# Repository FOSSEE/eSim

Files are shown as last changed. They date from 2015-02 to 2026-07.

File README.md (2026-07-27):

<p align="center">
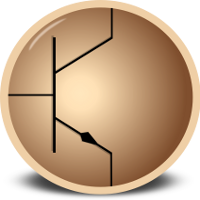
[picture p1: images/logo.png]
eSim Logo
  
</p>

<h1 align="center">eSim — Electronic Circuit Simulation</h1>

<p align="center">
  <strong>An Open-Source EDA Tool for Circuit Design, Simulation, Analysis &amp; PCB Design</strong><br/>
  <em>Developed by <a href="https://www.fossee.in/">FOSSEE Team</a> at <a href="https://www.iitb.ac.in/">IIT Bombay</a></em>
</p>

<p align="center">
  
  
  
  
</p>

<p align="center">
  
  
  
  
  
  
  
</p>

<p align="center">
  <a href="#-features">Features</a> •
  <a href="#%EF%B8%8F-architecture">Architecture</a> •
  <a href="#-installation">Installation</a> •
  <a href="#-project-structure">Project Structure</a> •
  <a href="#-tech-stack">Tech Stack</a> •
  <a href="#-contributing">Contributing</a> •
  <a href="#-license">License</a>
</p>

---

## 📖 About

**eSim** is a free and open-source EDA (Electronic Design Automation) tool for circuit design, simulation, analysis, and PCB design. It is an integrated tool built using open-source software such as **KiCad**, **Ngspice**, **GHDL**, and **Makerchip**, providing a seamless workflow from schematic capture to simulation results.

eSim is designed for electronics engineers, students, educators, and hobbyists who want a powerful yet cost-free alternative to proprietary EDA tools. It supports analog, digital, and **mixed-signal simulations**, including microcontroller integration.

<p align="center">
  <b>📥 Download:</b> <a href="https://esim.fossee.in/downloads">v2.5 Release</a> &nbsp;&nbsp;|&nbsp;&nbsp; 
  <b>📄 Manual:</b> <a href="https://static.fossee.in/esim/manuals/eSim_Manual_2.5.pdf">PDF Guide</a> &nbsp;&nbsp;|&nbsp;&nbsp; 
  <b>📚 Docs:</b> <a href="https://esim.readthedocs.io/en/latest/">ReadTheDocs</a>
</p>

---

## ✨ Features

| Category | Feature | Description |
|:---|:---|:---|
| • **Design** | Schematic Capture | Draw circuit schematics using KiCad's schematic editor with eSim's custom symbol libraries |
| • **Conversion** | KiCad to Ngspice | Convert KiCad schematics to Ngspice-compatible netlists for simulation |
| • **Simulation** | Ngspice Engine | Run DC, AC, Transient, and other SPICE analyses with real-time interactive plots |
| • **Analysis** | Waveform Plotting | Visualize simulation results with matplotlib-based Python plots and Ngspice native plots |
| • **Model Editor** | Device Models | Create and edit SPICE device models (Diodes, BJTs, MOSFETs, JFETs, IGBTs, etc.) |
| • **Subcircuits** | Subcircuit Builder | Build, manage, and upload reusable subcircuit blocks — **741+ ICs** in `SubcircuitLibrary` |
| • **Mixed-Signal** | NGHDL Integration | Interface VHDL digital models (via GHDL) with analog Ngspice simulations |
| • **Verilog** | Makerchip + NgVeri | Use Makerchip IDE for Verilog/TL-Verilog design and convert to Ngspice models |
| • **PCB** | Layout Design | Design PCB layouts using KiCad's PCB editor with eSim's footprint libraries |
| • **Converters** | Schematic Import | Convert PSpice and LTSpice schematics/libraries to KiCad-compatible formats |
| • **Modelica** | Ngspice-to-Modelica | Convert Ngspice netlists to Modelica models for OpenModelica simulation |
| • **SKY130 PDK** | SkyWater 130nm | Support for SkyWater SKY130 open-source Process Design Kit |
| • **IHP PDK** | IHP OpenPDK | Integration with IHP SG13G2 open-source PDK for SiGe BiCMOS |

---

## 🏗️ Architecture

### High-Level System Architecture

```mermaid
graph TB
    %% Styling
    classDef ui fill:#2A3F54,stroke:#1ABB9C,stroke-width:2px,color:#fff
    classDef core fill:#3E536C,stroke:#3498DB,stroke-width:2px,color:#fff
    classDef engine fill:#1F2D3D,stroke:#E74C3C,stroke-width:2px,color:#fff
    classDef data fill:#E9F0F5,stroke:#95A5A6,stroke-width:1px,color:#333
    
    subgraph UI ["User Interface (PyQt6)"]
        A[Application Main Window]:::ui
        PE[Project Explorer]:::ui
        DA[Dock Area Workspace]:::ui
        TE[Time Explorer]:::ui
        CON[Console Widget]:::ui
        
        A --> PE & DA & TE & CON
    end

    subgraph CORE ["Core Python Modules"]
        K2N[KiCad-to-Ngspice]:::core
        SIM[Ngspice Simulator]:::core
        PLT[Matplotlib Plotter]:::core
        ME[Model Editor]:::core
        SC[Subcircuit Builder]:::core
        
        DA --> K2N & SIM & ME & SC
    end

    subgraph INTEGRATION ["Mixed-Signal & External APIs"]
        NGHDL[NGHDL Interface]:::core
        MKR[Makerchip/NgVeri]:::core
        MOD[Modelica Converter]:::core
        CONV[PSpice/LTSpice Converter]:::core
        
        DA --> NGHDL & MKR & MOD & CONV
    end

    subgraph ENGINES ["Simulation & EDA Engines"]
        KICAD[KiCad Eeschema]:::engine
        PCB[KiCad Pcbnew]:::engine
        NGSPICE[Ngspice Backend]:::engine
        GHDL[GHDL Simulator]:::engine
        VER[Verilator]:::engine
        OM[OpenModelica]:::engine
    end

    %% Data Flow
    XML[(Netlist / XML)]:::data
    RAW[(Raw Data / txt)]:::data
    VHDL[(VHDL Files)]:::data
    
    K2N -- Generates --> XML
    XML -- Consumed by --> NGSPICE
    SIM -- Triggers --> NGSPICE
    NGSPICE -- Outputs --> RAW
    RAW -- Parsed by --> PLT
    
    NGHDL -- Compiles --> VHDL
    VHDL -- Simulated by --> GHDL
    GHDL -- Co-simulates --> NGSPICE
    
    MKR -- Verilog/TL-V --> VER
    
    KICAD -- Schematic --> K2N
    KICAD -- Netlist --> PCB
```

*For detailed simulation workflows, sub-system operations, and system flowcharts, please refer to our [Architecture & Workflows Guide](ARCHITECTURE.md).*

---

## 📂 Project Structure

### Root Directory

| Path | Type | Description |
|:-----|:-----|:---|
| `src/` | 📁 Directory | **Core application source code** — all Python modules for the eSim GUI and backend |
| `library/` | 📁 Directory | **Component libraries** — device models, KiCad symbols, subcircuits, and PDK data |
| `nghdl/` | 📁 Directory | **NGHDL module** — Ngspice-GHDL interface for mixed-signal VHDL simulation |
| `Examples/` | 📁 Directory | **42 example projects** — ready-to-simulate circuits (RC, BJT, Op-Amp, Mixed-Signal, etc.) |
| `images/` | 📁 Directory | **UI assets** — application icons, toolbar images, logos, and splash screen |
| `scripts/` | 📁 Directory | **Launch & setup scripts** — shell scripts for Linux installation and launching |
| `docs/` | 📁 Directory | **Sphinx documentation** — RST files for ReadTheDocs auto-generated developer docs |
| `code/` | 📁 Directory | **Sphinx autodoc config** — mirrors `src/` structure for API documentation generation |
| `flatpak/` | 📁 Directory | **Flatpak packaging** — manifest and wrapper scripts for universal Linux distribution |
| `appimage/` | 📁 Directory | **AppImage packaging** — build scripts for portable Linux AppImage bundles |
| `docker-launcher/` | 📁 Directory | **Docker support** — Dockerfile, launcher script, and CI workflows for containerized builds |
| `snap/` | 📁 Directory | **Snap packaging** — `snapcraft.yaml` for building Snap packages |
| `ihp/` | 📁 Directory | **IHP PDK integration** — install script, `.spiceinit` config, NMOS example, and ngspice latest installer for IHP SG13G2 SiGe BiCMOS PDK |
| `patches/` | 📁 Directory | **Source patches** — patch files for modifying Ngspice/GHDL behavior in sandboxed environments |
| `.github/` | 📁 Directory | **GitHub config** — issue templates, PR templates, and CI/CD workflow definitions |
| `setup.py` | 📄 File | Python package configuration for pip installation |
| `requirements.txt` | 📄 File | Python dependency list (PyQt6, matplotlib, numpy, scipy, etc.) |
| `conf.py` | 📄 File | Sphinx documentation configuration |
| `VERSION` | 📄 File | Current version identifier (`2.5`) |
| `INSTALL` | 📄 File | Detailed multi-platform installation instructions |
| `LICENSE` | 📄 File | GNU General Public License v3.0 |

### Source Code (`src/`) — Detailed Module Breakdown

```
src/
├── frontEnd/               # GUI & Main Application
│   ├── Application.py      # Main window, toolbar setup, menu actions (960 lines)
│   ├── DockArea.py          # Tabbed dock workspace for editors/simulators (24K)
│   ├── ProjectExplorer.py   # File tree browser for project navigation (20K)
│   ├── TimeExplorer.py      # Project snapshot/version management (8K)
│   ├── TerminalUi.py        # Embedded terminal widget (5K)
│   └── Workspace.py         # Workspace selection dialog (6K)
│
├── kicadtoNgspice/          # KiCad-to-Ngspice Conversion Engine
│   ├── KicadtoNgspice.py    # Main conversion controller & UI (41K)
│   ├── Convert.py           # Netlist parsing and SPICE generation (40K)
│   ├── Analysis.py          # Analysis type configuration (DC, AC, Transient) (32K)
│   ├── DeviceModel.py       # Device model parameter handling (56K)
│   ├── Source.py             # Source component configuration (15K)
│   ├── Processing.py         # Netlist processing pipeline (26K)
│   ├── SubcircuitTab.py      # Subcircuit selection in converter (9K)
│   ├── Microcontroller.py    # Microcontroller model support (10K)
│   ├── Model.py              # Model file handling (6K)
│   └── TrackWidget.py        # UI tracking widget (1K)
│
├── ngspiceSimulation/       # Simulation Engine & Plotting
│   ├── NgspiceWidget.py     # Ngspice process management & execution (16K)
│   ├── plot_window.py       # matplotlib-based waveform plotter (66K)
│   ├── plotting_widgets.py  # Custom plot controls and widgets (8K)
│   └── data_extraction.py   # Simulation data file parser (11K)
│
├── modelEditor/             # SPICE Model Editor
│   └── ModelEditor.py       # GUI for creating/editing device models (33K)
│
├── subcircuit/              # Subcircuit Management
│   ├── Subcircuit.py        # Subcircuit manager main window (3K)
│   ├── newSub.py            # Create new subcircuit (3K)
│   ├── openSub.py           # Open existing subcircuit (1K)
│   ├── uploadSub.py         # Upload subcircuit to library (4K)
│   └── convertSub.py        # Subcircuit format conversion (2K)
│
├── maker/                   # Makerchip & NgVeri Integration
│   ├── Maker.py             # Makerchip IDE integration (23K)
│   ├── NgVeri.py            # Verilog-to-Ngspice model generator (17K)
│   ├── ModelGeneration.py   # Auto model generation pipeline (48K)
│   ├── createkicad.py       # KiCad symbol creation for models (14K)
│   ├── makerchip.py         # Makerchip cloud IDE connector (3K)
│   └── Appconfig.py         # Maker-specific configuration (2K)
│
├── converter/               # Schematic Format Converters
│   ├── pspiceToKicad.py     # PSpice schematic importer (5K)
│   ├── ltspiceToKicad.py    # LTSpice schematic importer (6K)
│   ├── libConverter.py      # Library format converter (3K)
│   ├── LtspiceLibConverter.py # LTSpice library converter (4K)
│   ├── browseSchematic.py   # File browser for schematics (550B)
│   ├── LTSpiceToKiCadConverter/ # LTSpice conversion engine
│   └── schematic_converters/    # Additional schematic parsers
│
├── ngspicetoModelica/       # 📐 Ngspice-to-Modelica Converter
│   ├── NgspicetoModelica.py # Core conversion engine (54K)
│   └── ModelicaUI.py        # Modelica converter GUI (10K)
│
├── configuration/           # ⚙️ Application Configuration
│   └── Appconfig.py         # Global config, paths, process tracking (4K)
│
├── projManagement/          # 📋 Project Management
│   ├── Kicad.py             # KiCad integration (launch schematic/PCB editor) (9K)
│   ├── Validation.py        # Tool and file validation utilities (7K)
│   ├── Worker.py            # Background process/thread management (3K)
│   ├── newProject.py        # New project creation logic (5K)
│   └── openProject.py       # Open existing project logic (3K)
│
└── browser/                 # 📖 Help & Documentation
    ├── Welcome.py           # Welcome screen display (941B)
    └── UserManual.py        # User manual viewer (731B)
```

### Library Directory (`library/`) — Component Libraries

| Path | Description |
|:-----|:---|
| `deviceModelLibrary/` | SPICE device models organized by type: Diode, BJT (Transistor), MOSFET (MOS), JFET, IGBT, LEDs, Switches, Transmission Lines, and user libraries |
| `kicadLibrary/` | KiCad schematic symbols (`eSim-symbols/`), footprint libraries (`kicad_eSim-Library/`), and project templates |
| `SubcircuitLibrary/` | **741+ reusable subcircuit ICs** — logic gates, flip-flops, op-amps, regulators, timers, multiplexers, shift registers, comparators, multipliers, PDK-specific IPs, and more (see [Subcircuit Library](#-subcircuit-library) section) |
| `modelParamXML/` | XML parameter definitions for device model editor forms |
| `ngspicetoModelica/` | Mapping files for Ngspice-to-Modelica component translation |
| `browser/` | HTML/resource files for the built-in help browser |
| `tlv/` | TL-Verilog support files for Makerchip integration |

### NGHDL Module (`nghdl/`) — Mixed-Signal Interface

| Path | Description |
|:-----|:---|
| `src/ngspice_ghdl.py` | Core interface: manages VHDL upload, GHDL compilation, and Ngspice code model creation |
| `src/model_generation.py` | Generates C code models from VHDL port definitions for Ngspice |
| `src/createKicadLibrary.py` | Auto-generates KiCad symbols from VHDL entity definitions |
| `src/ghdlserver/` | GHDL foreign interface server for inter-process communication with Ngspice |
| `install-nghdl.sh` | Automated installer for NGHDL dependencies (GHDL, Verilator, Ngspice) |
| `Example/` | Example VHDL models and mixed-signal simulation projects (including **Microwatt NGHDL co-simulation**) |

### IHP PDK Integration (`ihp/`) — SiGe BiCMOS Open PDK

| Path | Description |
|:-----|:---|
| `ihp-install-script.sh` | Automated installer for IHP SG13G2 open-source SiGe BiCMOS PDK |
| `install-ngspice-latest.sh` | Script to build and install the **latest ngspice** from source (with OSDI support) — requires eSim/NGHDL to be installed first |
| `.spiceinit` | Pre-configured `.spiceinit` file for IHP-Open-PDK; automatically placed in the home directory after configuration |
| `example.cir` | NMOS DC test circuit demonstrating IHP PDK SPICE simulation |

---

## 🛠️ Tech Stack

| Layer | Technology | Purpose |
|:---|:---|:---|
| **Language** |  | Core application logic |
| **GUI Framework** |  | Desktop GUI (windows, dialogs, toolbars, docks) |
| **Plotting** |  | Waveform visualization and data plotting |
| **Numerics** |   | Numerical computation and signal processing |
| **Schematic & PCB** |  | Schematic capture and PCB layout design |
| **SPICE Simulation** |  | Analog/mixed-signal circuit simulation engine |
| **VHDL Simulation** |  | VHDL analysis, compilation, and simulation |
| **Verilog** |  | Verilog HDL simulation and model generation |
| **HDL Cloud IDE** |  | Online Verilog/TL-Verilog IDE integration |
| **Modelica** |  | Multi-domain modeling and simulation |
| **PDK** |   | SkyWater 130nm & IHP SiGe BiCMOS open-source PDKs |
| **Packaging** |   | Cross-distribution Linux packaging & containers |
| **Documentation** |   | Auto-generated developer documentation |
| **CI/CD** |  | Automated builds, Docker images, and releases |

### Key Python Dependencies

| Package | Version | Purpose |
|:---|:---|:---|
| `PyQt6` | ≥ 6.5.0 | GUI framework |
| `matplotlib` | 3.7.5 | Waveform plotting |
| `numpy` | 1.24.4 | Numerical computation |
| `scipy` | 1.10.1 | Scientific computing |
| `pillow` | 12.2.0 | Image processing |
| `hdlparse` | 1.0.4 | HDL file parsing |
| `watchdog` | 4.0.2 | File system monitoring |
| `pyparsing` | 3.1.4 | Parser building toolkit |

---

## 💻 Installation

### Supported Platforms

| Platform | Method | Status |
|:---|:---|:---:|
| **All Linux** (Fedora, Ubuntu, openSUSE, Arch, etc.) | Flatpak | ✅ Recommended |
| **Ubuntu** 22.04 / 23.04 / 24.04 LTS | Native Installer | ✅ Supported |
| **Windows** 8 / 10 / 11 | Windows Installer | ✅ Supported |
| **Docker** (any OS) | Docker Container | ✅ Supported |

### 🐧 Linux — Flatpak (Recommended for all distributions)

```bash
# 1. Install Flatpak (if not already installed)
# Fedora:    sudo dnf install flatpak
# Ubuntu:    sudo apt install flatpak
# openSUSE:  sudo zypper install flatpak
# Arch:      sudo pacman -S flatpak

# 2. Add Flathub repository
flatpak remote-add --if-not-exists flathub https://dl.flathub.org/repo/flathub.flatpakrepo

# 3. Install eSim
flatpak install flathub org.fossee.eSim

# 4. Run eSim
flatpak run org.fossee.eSim
```

> **⚠️ Flatpak Limitations:** NGHDL, Makerchip, and SKY130 PDK are not included in the Flatpak build. For full mixed-signal support, use the Ubuntu native installer.

### 🐧 Ubuntu — Native Installer

```bash
# 1. Download and extract eSim
unzip eSim-2.5.zip
cd eSim-2.5

# 2. Install eSim with all dependencies
chmod +x install-eSim.sh
./install-eSim.sh --install

# 3. Run eSim
esim
# Or double-click the eSim desktop icon
```

### 🪟 Windows

1. Download the eSim installer from [esim.fossee.in/downloads](https://esim.fossee.in/downloads)
2. Disable antivirus temporarily (if required)
3. **Important:** Remove MinGW/MSYS from the PATH environment variable if previously installed
4. Run the installer and follow the on-screen instructions
5. Launch eSim from the Start Menu or desktop shortcut

### 🐋 Docker

Refer to the [Docker Launcher README](docker-launcher/README.md) for instructions on running eSim in a containerized environment.

> **Note:** The Docker image now includes `libreadline-dev` to fix a build issue on recent Ubuntu base images.

### 📦 Build from Source (Flatpak)

```bash
cd eSim
flatpak-builder build flatpak/org.fossee.eSim.yml --install --user
```

> 📖 For comprehensive installation instructions, see the [INSTALL](INSTALL) file.

### ⚗️ IHP PDK — Latest Ngspice from Source

If you need the latest Ngspice with OSDI support for IHP PDK simulations:

```bash
# Requires eSim/NGHDL to be installed first
chmod +x ihp/install-ngspice-latest.sh
./ihp/install-ngspice-latest.sh
```

---

## 🔄 CI/CD & Packaging

| Workflow | File | Purpose |
|:---|:-----|:---|
| Docker Image Build | `.github/workflows/docker-image.yml` | Builds and publishes the eSim Docker image |
| Docker Launcher Build | `.github/workflows/docker-launcher-build.yml` | Builds the cross-platform Python launcher |
| Ubuntu Release | `.github/workflows/release_ubuntu.yml` | Automated Ubuntu `.deb` package builds |

| Packaging Format | Directory | Description |
|:---|:---|:---|
| Flatpak | `flatpak/` | Universal Linux package via Flathub |
| AppImage | `appimage/` | Portable single-file Linux executable |
| Snap | `snap/` | Ubuntu Snap Store package |
| Docker | `docker-launcher/` | Containerized distribution with GUI forwarding |

---

## 📋 Example Projects

eSim ships with **42 ready-to-simulate example projects** in the `Examples/` directory:

<details>
<summary><b>📂 Click to expand full example list</b></summary>

| # | Category | Example | Description |
|:-:|:---|:---|:---|
| 1 | 🔌 Basic | `RC` | RC circuit transient analysis |
| 2 | 🔌 Basic | `RL` | RL circuit transient analysis |
| 3 | 🔌 Basic | `RLC` | RLC circuit resonance analysis |
| 4 | 🔌 Basic | `Series_Resonance` | Series RLC resonance |
| 5 | 🔌 Basic | `Parallel_Resonance` | Parallel RLC resonance |
| 6 | 💡 Diodes | `Diode_characteristics` | Diode I-V characteristics |
| 7 | 💡 Diodes | `Halfwave_Rectifier` | Half-wave rectifier circuit |
| 8 | 💡 Diodes | `Fullwavebridgerectifier` | Full-wave bridge rectifier |
| 9 | 💡 Diodes | `Clippercircuit` | Diode clipper circuit |
| 10 | 💡 Diodes | `Clampercircuit` | Diode clamper circuit |
| 11 | 💡 Diodes | `Zener_Characteristic` | Zener diode characteristics |
| 12 | 🔋 BJT | `BJT_CE_config` | BJT common-emitter configuration |
| 13 | 🔋 BJT | `BJT_CB_config` | BJT common-base configuration |
| 14 | 🔋 BJT | `BJT_amplifier` | BJT amplifier circuit |
| 15 | 🔋 BJT | `BJT_Biascircuit` | BJT bias circuit design |
| 16 | 🔋 BJT | `BJT_Frequency_Response` | BJT frequency response analysis |
| 17 | 📟 FET | `FET_Characteristic` | FET output characteristics |
| 18 | 📟 FET | `FET_Amplifier` | FET amplifier circuit |
| 19 | 📟 FET | `FrequencyResponse_JFET` | JFET frequency response |
| 20 | 🎛️ Op-Amp | `InvertingAmplifier` | Op-amp inverting amplifier (LM741) |
| 21 | 🎛️ Op-Amp | `Differentiator` | Op-amp differentiator circuit |
| 22 | 🎛️ Op-Amp | `Integrator_LM_741` | Op-amp integrator |
| 23 | 🎛️ Op-Amp | `Precision_Rectifiers_using_LM741` | Precision rectifier circuits |
| 24 | 🔲 Digital | `BasicGates` | Basic logic gates |
| 25 | 🔲 Digital | `Half_Adder` | Half-adder circuit |
| 26 | 🔲 Digital | `FullAdder` | Full-adder circuit |
| 27 | 🔲 Digital | `JK_Flipflop` | JK flip-flop circuit |
| 28 | 🔲 Digital | `4_bit_JK_ff` | 4-bit JK flip-flop counter |
| 29 | 🔲 Digital | `CMOS_NAND_Gate` | CMOS NAND gate |
| 30 | 🔲 Digital | `Analysis_Of_Digital_IC` | Digital IC analysis |
| 31 | ⏱️ Timers | `Astable555` | 555 timer astable mode |
| 32 | ⏱️ Timers | `Monostable555` | 555 timer monostable mode |
| 33 | 🔁 SCR | `HalfwaveRectifier_SCR` | SCR half-wave rectifier |
| 34 | 🔁 SCR | `FullwaveRectifier_SCR` | SCR full-wave rectifier |
| 35 | 📡 Filters | `High_Pass_Filter` | High-pass filter design |
| 36 | 📡 Filters | `Low_Pass_Filter` | Low-pass filter design |
| 37 | ⚡ Regulators | `7805VoltageRegulator` | 7805 voltage regulator |
| 38 | ⚡ Regulators | `7812VoltageRegulator` | 7812 voltage regulator |
| 39 | 🌀 Oscillators | `UJT_Relaxation_Oscillator` | UJT relaxation oscillator |
| 40 | 🌀 Oscillators | `Phase_Locked_Loop` | PLL circuit |
| 41 | 🔀 Mixed-Signal | `Mixed_Signal` | Mixed analog-digital simulation (NGHDL) |
| 42 | 🔌 Power | `Transformer` | Transformer circuit analysis |

</details>

---

## 📦 Subcircuit Library

The `library/SubcircuitLibrary/` directory contains **741+ verified subcircuit models** contributed by the community. These can be directly used in eSim simulations as subcircuit blocks.

<details>
<summary><b>📂 Click to expand subcircuit categories</b></summary>

| Category | Examples |
|:---|:---|
| **Logic Gates & Buffers** | 74HC08, 74HC32, 74HC86, SN74LS00, IC74HC00, INVCMOS, CMOS_NAND, SNx4HC03 |
| **Flip-Flops & Latches** | 74LS379, CD4095BMS, JK flip-flops (74LS112, IC74HC107), D flip-flops, SR latches |
| **Shift Registers** | 74hc589, 74HCT594, 74LS298, 74LS399, SN74LS295B, SN74LS194 |
| **Multiplexers / Demultiplexers** | 74LS150 (16:1 MUX), 74HC157, CD4051_sub, SN74LS451, 74ls670 |
| **Counters & Dividers** | CD4017B, CD4026B, CD4029B, 74ls93, 74ls181, SN74LS461, DM74ls173 |
| **Encoders / Decoders** | SN74LS247, SN74LS353, MM74C923, CD4099B, CD4089B, LM3914 |
| **Op-Amps & Comparators** | LM358_Sub, LM741, LM311, LM393, LT1010, lmh6702, opa656, ths4303, ths4541 |
| **Voltage Regulators** | LM7806, LM7812, LP2950, LP2951, LM317_sub, MCP1700, TCA965, MC1569_Sub |
| **Audio Amplifiers** | MC1306_Sub, MC1554_Sub, LM386, LM833, TDA2003A_sub |
| **RF / IF Amplifiers** | MC1510_sub, MC1545_Sub, MC1550_Sub, vca821 |
| **Multipliers & Modulators** | ad834, ad8307, MC1595_Sub, MC1596_Sub, cppll |
| **Motor Drivers & Power ICs** | L298N, IR2110, IR2130, IP5328P, TP4056, MCP73831, TL494 |
| **CA-Series ICs** | CA3005, CA3018, CA3019, CA3022, CA3028A, CA3036, CA3054, CA3080, CA3094 |
| **SN74-Series ICs** | SN74AS303, SN74AS304, SN74AS305, SN74LS247, SN74LS451, SN74S268, SN74S532, SN74S536, SN74278 |
| **MC-Series ICs** | MC1306_Sub, MC1510_sub, MC1545_Sub, MC1550_Sub, MC1554_Sub, MC1569_Sub, MC1595_Sub, MC1596_Sub |
| **CD/CMOS Series** | CD4016, CD4026B, CD4029B, CD4089B, CD4095BMS, CD4099B, CD74HC563, CD74HCT241 |
| **ADC / DAC** | 3bit_flash_adc, DAC0800, 10bitDAC |
| **Timers** | NE556 (dual 555), lm555n, MC1455B_IC |
| **Miscellaneous** | SN54170, LM2902, LM2904, LM2917, LM2941, TL783, _TL783 |

</details>

> 💡 **Contributing a Subcircuit?** Follow the guidelines in [CONTRIBUTING.md](CONTRIBUTING.md). Each subcircuit should include a `.sub` SPICE file, a KiCad schematic (`.kicad_sch`), and a test circuit (`.cir`).

---

## 🤝 Contributing

We welcome contributions from the community! Whether it's bug fixes, new features, documentation improvements, or example circuits — every contribution matters.

### How to Contribute

```mermaid
flowchart LR
    A["🍴 Fork<br/>Repository"] --> B["🌿 Create<br/>Branch"]
    B --> C["💻 Make<br/>Changes"]
    C --> D["✅ Commit &<br/>Push"]
    D --> E["📬 Open<br/>Pull Request"]

    style A fill:#6c5ce7,color:#fff
    style B fill:#00b894,color:#fff
    style C fill:#0984e3,color:#fff
    style D fill:#fdcb6e,color:#333
    style E fill:#e17055,color:#fff
```

1. **Fork** the repository to your GitHub account
2. **Clone** your fork:
   ```bash
   git clone https://github.com/<your-username>/eSim.git
   ```
3. **Create a new branch** for your changes:
   ```bash
   git checkout -b feature/your-feature-name
   ```
4. **Make your changes** and commit with a descriptive message:
   ```bash
   git add <files>
   git commit -m "Fixes issue #<number> - Brief description of changes"
   ```
5. **Push** to your fork and **open a Pull Request**:
   ```bash
   git push origin feature/your-feature-name
   ```

> **📌 Guidelines:**
> - Each PR should reference an existing issue
> - One commit per pull request (squash if needed)
> - Follow [PEP 8](https://www.python.org/dev/peps/pep-0008/) code style
> - Include a commit body describing what you changed and why

For detailed contribution guidelines, see [CONTRIBUTING.md](CONTRIBUTING.md).

---

## 👥 Contributors

A huge thank you to all **149+ amazing people** who have contributed to eSim! 🎉

<table align="center" style="border:none;">
  <tr>
    <td align="center" width="250" style="border:none;">
      <a href="https://github.com/Eyantra698Sumanto" style="text-decoration:none;">
        Sumanto Kar<br/>
        <b>🥇 Sumanto Kar</b>
      </a><br/>
      <sub>Lead Maintainer · 320 commits</sub>
    </td>
    <td align="center" width="250" style="border:none;">
      <a href="https://github.com/rahulp13" style="text-decoration:none;">
        Rahul Paknikar<br/>
        <b>🥈 Rahul Paknikar</b>
      </a><br/>
      <sub>265 commits</sub>
    </td>
    <td align="center" width="250" style="border:none;">
      <a href="https://github.com/fahim-oscad" style="text-decoration:none;">
        Fahim Khan<br/>
        <b>🥉 Fahim Khan</b>
      </a><br/>
      <sub>244 commits</sub>
    </td>
  </tr>
</table>

<p align="center">
  <a href="https://github.com/fossee/esim/graphs/contributors">
    Contributors
  </a>
</p>

<p align="center"><em>149+ contributors and counting! <a href="https://github.com/fossee/esim/graphs/contributors">View all contributors →</a></em></p>

---

## 📞 Contact & Support

| Channel | Link |
|:---|:-----|
| 📧 **Email** | [contact-esim@fossee.in](mailto:contact-esim@fossee.in) |
| 🌐 **Website** | [esim.fossee.in](https://esim.fossee.in/) |
| 💬 **Forum** | [forums.fossee.in](https://forums.fossee.in/) |
| 📞 **Contact Page** | [esim.fossee.in/contact-us](https://esim.fossee.in/contact-us) |
| 📄 **User Manual** | [eSim Manual v2.5 (PDF)](https://static.fossee.in/esim/manuals/eSim_Manual_2.5.pdf) |
| 📚 **Developer Docs** | [esim.readthedocs.io](https://esim.readthedocs.io/en/latest/) |

---

## 📝 Recent Changes

A summary of notable changes since the last README update (June 2026):

### 🔧 IHP PDK Enhancements (June 2026)
- Added `ihp/install-ngspice-latest.sh` — a script to build the latest Ngspice from source with OSDI support for IHP PDK users
- Added `ihp/.spiceinit` — pre-configured Ngspice initialization file for IHP-Open-PDK; the install script now correctly places it in the user's home directory
- Added `ihp/example.cir` — an NMOS DC test circuit demonstrating IHP PDK simulation

### 🧩 Subcircuit Library Expansion (June–July 2026)
Over **100 new subcircuit ICs** were contributed and verified, bringing the total to **741+** entries in `library/SubcircuitLibrary/`. Highlights include:
- **CA-series ICs**: CA3005, CA3018, CA3019, CA3022, CA3028A, CA3036, CA3054 (and moved CA3020, CA3021, etc. from misplaced locations)
- **MC-series analog ICs**: MC1306_Sub (audio amp), MC1510_sub (RF/IF amp), MC1545_Sub (video amp), MC1550_Sub (RF/IF amp), MC1554_Sub (audio amp), MC1569_Sub (voltage regulator), MC1595_Sub (4-quadrant multiplier), MC1596_Sub (balanced modulator/demodulator)
- **Analog ICs from PR #604 (Farhana)**: LT1010, vca821, ths4541, ths4303, opa656, lmh6702, cppll, ad834, ad8307, 3bit_flash_adc
- **Power/control ICs**: L298N (motor driver), IR2110, IR2130 (gate drivers), IP5328P (power bank IC), TP4056 (Li-ion charger), MCP73831 (Li-Po charger), TL494 (PWM controller), TL783, LP2950, LP2951
- **Voltage regulators**: LM2941, LM7806, MCP1700, TCA965
- **Op-amps / comparators**: LM2902, LM2904, LM2917, LM1815
- **SN74-series digital ICs**: SN74AS303/304/305, SN74LS247, SN74LS295B, SN74LS353, SN74LS451, SN74LS461, SN74LS498, SN74S268, SN74S532, SN74S536, SN74278
- **TTL/CMOS logic**: 74LS112, 74LS150, 74LS298, 74LS379, 74LS399, 74hc589, 74HCT594, CD4095BMS, CD4016, CD4026B, CD4029B, CD4089B, CD4099B, SN54170, MM74C923, LM3914
- **Additional digital ICs**: 74ls93, 74ls175, 74ls181, 74ls374, 74ls670, 74lv157, DM74ls173, sn74ls244, sn5470, 4024bc

### 🔀 Library Reorganization (July 2026)
- **PR #591**: Cleaned up misplaced subcircuits — moved `CA3020`, `LM108`, `LM3080`, `MC1496`, `NE556`, `TL03xA`, `UA702M` from a duplicate location into the canonical `library/SubcircuitLibrary/` path
- **Subcircuit files** from `SUBCKT/` directory moved to `library/SubcircuitLibrary/` (June 2026)

### 🔬 NGHDL — New Microwatt Example (June 2026)
- Added a **Microwatt NGHDL co-simulation example** in `nghdl/Example/` demonstrating mixed-signal simulation with the open-source Microwatt POWER ISA soft-core processor (via PR #569)

### 🐋 Docker — Build Fix (June 2026)
- Added `libreadline-dev` to the Dockerfile to resolve a build failure on newer Ubuntu base images

### 🛠️ Bug Fix — Workspace Newline (June 2026)
- Fixed workspace newline handling issue (PR #469)

---

## 📄 License

eSim is licensed under the **GNU General Public License v3.0**. See [LICENSE](LICENSE) for details.

<p align="center">
  <strong>Built with ❤️ by the <a href="https://www.fossee.in/">FOSSEE Team</a> at <a href="https://www.iitb.ac.in/">IIT Bombay</a></strong>
</p>

<p align="center">
  <a href="https://esim.fossee.in/">
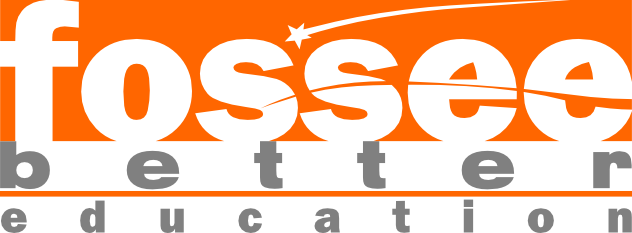
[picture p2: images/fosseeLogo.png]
FOSSEE Logo
    
  </a>
  &nbsp;&nbsp;&nbsp;&nbsp;
  <a href="https://www.iitb.ac.in/">
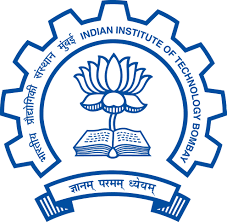
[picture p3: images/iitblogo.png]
IIT Bombay Logo
    
  </a>
</p>

<p align="center">
  <sub>⭐ If you find eSim useful, consider giving it a star on GitHub!</sub>
</p>

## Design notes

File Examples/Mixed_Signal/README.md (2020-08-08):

Instructions on how to use the following examples provided in this directory:

These examples are supported by the NGHDL feature.
In order to simulate the examples listed above, follow the below instructions.

1. Go to eSim main window -> Click on NGHDL icon from the left toolbar, click on the 'browse' button, go to ../nghdl/Example/ and locate which example you wish to simulate.
2. After opening the directory of desired example, locate the vhdl file, click on the "Open" button at the bottom of "Open File" window.
3. Click on 'upload' button in the NGHDL pop-up window. File will be processed in the backend for few seconds. Now exit the NGHDL window.
4. Open the desired example under eSim/Examples/Mixed_Signal/ using the Open Project button, double click on the project when the project is loaded in the "Projects" window.
5. Click on the "Simulation" button on eSim main window.

More examples will be added by eSim team along the way.
If you have a good command on VHDL and electronics, please feel free to contribute.

Note : The Examples in this directory are for demonstration purpose of eSim's Mixed-Signal Simulation feature executing as expected.

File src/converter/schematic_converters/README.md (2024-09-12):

# eSim_PSpice_to_KiCad_Python_Parser

This code is written by Suryavamsi Tenetti, FOSSEE, IIT Bombay and modified by Sumanto Kar and Gloria Nandihal, FOSSEE, IIT Bombay.

This program converts PSpice schematic files (.sch) to KiCad schematic files (.sch)

This program converts PSpice library files (.slb) to KiCad library files (.lib)

USAGE:

-----------------------------------------------
**Make sure the python 3 compiler is installed in the PC**

Run the following command in the terminal in order to install it.

$ sudo apt install python3.7

-----------------------------------------------
**To download the eSim_PSpice_to_KiCad_Python_Parser**

Clone or Download the *eSim_PSpice_to_KiCad_Python_Parser* from the Git in the Home folder(or any other folder) of the local computer.

-----------------------------------------------
**To convert the PSpice library(.slb) files to KiCad library(.lib) files**

Set the path where the *libparser.py* file is located. It is located at */eSim_PSpice_to_KiCad_Python_Parser/lib/PythonLib*

$ python3 libParser.py <path to the pspice lib file(slb)> <output_library_name_without_extension> 

Example:
$ python3 libParser.py ~/Home/eSim_PSpice_to_KiCad_Python_Parser/libray/analog.slb analog

This will create analog.lib file and save it in the path </Home/eSim_PSpice_to_KiCad_Python_Parser/libray/>

-----------------------------------------------
**To convert the PSpice schematic files to KiCad schematic files**

Set the path where the *parser.py* file is located. It is located at */eSim_PSpice_to_KiCad_Python_Parser/lib/PythonLib*

$ python3 parser.py <path/to/pspice-schematic.sch> <path/to/output-project-name-without-extension>

Example:
$ python3 parser.py ~/Desktop/pspice/rc.sch ~/Desktop/convert/rc

This will create a folder rc at the location /Desktop/convert/. The directory will have  rc.sch, rc.proj and rc.pro.
The directory will have read only access. You need to use chmod command to change the access.

--------------------------------------------------------
**To change the access of the file and folder**

Use this command to change access to the files:

chmod <options> <permissions> <file name>
Example:
chmod u=rwx,g=rx,o=r myfile

You can also use: 

sudo chmod 777 filename.

Example: sudo chmod 777 ~/Desktop/convert/rc

-----------------------------------------------
**To open the KiCad schematic file in eSim** 

1. Open eSim.
2. Create a *new project*.
3. Open the schematic using *open schematic* option.
4. Make sure all the libraries are loaded (9k+) using *Place component* option in eeschema.
5. Append the schematic using *Append Schematic* option from the file menu
6. Go to the directory where your files are converted.
7. Select the KiCad coverted schematic file (.sch). Click on Open.
8. To simulate, follow the instructions available on the eSim webpage
    https://esim.fossee.in/pspice-to-kicad
-----------------------------------------------
**To load the KiCad libraries**

If all the libraries in eeschema are not loaded, follow these steps:
1. In eeschema, select *Preferences* option.
2. Click on the *Component Libraries* in the drop down list.
3. A dialog box appears, click on the *Add* option.
4. Go to the path where your library to be added is saved.
5. Select the library to be added and click on *Open* button.
6. Close the dialog box.
-----------------------------------------------
**To add libraries in the parser.py**

Open the *parser.py* python file. It is located at */eSim_PSpice_to_KiCad_Python_Parser/lib/PythonLib*
Type and add the libraries in the variables *"descr"* and *"prodescr"*

-----------------------------------------------
**WARNING**

1. Filenames should NOT contain whitespaces or tabs.
2. All required libraries SHOULD be added.
3. Use proper file format.
4. DO NOT TRY TO CONVERT library file as schematic file or vice versa.
5. Try adding libraries in the parser.py while getting error.
6. DO NOT CHANGE any of the files unless and until needed.

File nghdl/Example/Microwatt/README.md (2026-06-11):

# Microwatt eSim Integration

## Overview

This directory contains initial integration support for running the OpenPOWER Microwatt core inside the eSim/NGHDL co-simulation environment.

The integration flow enables Microwatt to be compiled with GHDL and wrapped for NGHDL/XSPICE-based simulation inside eSim.

## Files

### `microwatt_cosim.vhdl`

NGHDL-compatible wrapper for Microwatt.

Exposed ports:

* `clk` : Clock input
* `rst` : Reset input
* `uart_tx` : UART transmit output

### `compile_for_nghdl.sh`

Build script used to:

* Compile Microwatt using GHDL
* Build required helper objects
* Elaborate the wrapper for NGHDL/XSPICE integration

## Build Flow

Run:

```bash
bash esim/compile_for_nghdl.sh
```

Successful compilation generates the NGHDL-compatible elaborated design.

## eSim Workflow

1. Compile Microwatt using the provided script
2. Generate the NGHDL/XSPICE codemodel
3. Import the generated block into eSim
4. Create a schematic using:

   * clock pulse
   * reset pulse
   * UART probe
5. Run transient simulation

## Current Status

* Wrapper compilation successful
* NGHDL integration validated
* Basic schematic-level simulation setup completed

## Future Work

* Add memory and peripheral models
* Expand validation workflows
* Add example system-level designs

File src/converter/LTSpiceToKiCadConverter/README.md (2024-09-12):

# LTSpice To KiCad Converter by eSim Team

This code is referred from the following repository: https://github.com/laurentc2/LTspice2Kicad

This code is authored by Sumanto Kar, FOSSEE, IIT Bombay and the team members.

The repository contains program to convert LTSpice Schematics to KiCad Schematics.

The repository also contains program to convert LTSpice symbol files(.asy) to KiCad symbol files(.lib).

The code is supported by both Windows and Ubuntu(and flavors) Operating System.

## Cloning the repo:

To start with, please clone the repository:</br>
	```
	git clone https://github.com/FOSSEE/LTSpiceToKiCadConverter
	```

## Windows OS

### To Convert the Schematic file

1. Make sure python3 is installed and added to the path
2. Switch to src/Windows directory
3. Paste the LTspice file(.asc format) to be converted here
4. Double Click on the ```Sch_CreateBat.bat``` script
5. The LTspice schematic is converted to eSim(KiCad) schematic and project files
6. The files are saved in the src/Windows in a folder created with name ```LTspice_<schematic_name>```

-----------------------------------------------
### To Convert the .asy file to .lib file

1. Make sure python3 is installed and added to the path
2. Switch to src/Windows directory
3. Run the following command to convert the .asy files contained in a single folder to a .lib file:
	```
	python3 lib_LTspice2Kicad.py <Path to the folder containing the .asy files">
	```
	Example:
	```
	python3 lib_LTspice2Kicad.py "C:\Program Files\LTC\LTspiceXVII\lib\sym\DAC"
	```
	The .asy files will be converted a single .lib file with name LTspice_<folder_name>.lib. 
	For example: LTspice_DAC.lib</br>
4. To convert many folders containg .asy files:</br>
	- Edit the path in the ```lib_LTspice2Kicad.bat``` file using a text editor</br>
	- Save and close it</br>
	- Double click on the Batch files</br>
	- All the converted .lib files will be saved in the src/Windows

## Ubuntu OS

### To Convert the Schematic file

1. Make sure python3 is installed and added to the path
2. Switch to src/Ubuntu directory
3. Run the following command to convert the LTspice(.asc) files to KiCad Schematic(.sch, .pro and .proj) files:
    ```
    python3 sch_LTspice2Kicad.py <Path to the .asc file">
    ```
    For Example:
    ```
    python3 sch_LTspice2Kicad.py "/home/sumanto/Downloads/ltspice/ltspice/27C.asc"
    ```
4. The files are saved in a folder(in the same path where the original .asc file exists) created with name ```LTspice_<schematic_name>```

-----------------------------------------------
### To Convert the .asy file to .lib file

1. Make sure python3 is installed and added to the path
2. Switch to src/Ubuntu directory
3. Run the following command to convert the .asy files contained in a single folder to a .lib file:
	```
	python3 lib_LTspice2Kicad.py <Path to the folder containing the .asy files">
	```
	Example:
	```
	python3 lib_LTspice2Kicad.py "python3 lib_LTspice2Kicad.py /home/sumanto/Downloads/ltspice/libs/DAC"
	```
	The .asy files will be converted and save in src/Ubuntu to a single .lib file with name LTspice_<folder_name>.lib. 
	For example: LTspice_DAC.lib

-----------------------------------------------
### Example LTspice Schematics(.asc) and Symbol libraries(.asy)
The Example LTspice Schematics(.asc) and Symbol Libraries(.asy) are available in the LTspice software.

Please download the software from the official website.

## Converted KiCad Schematics(.sch, .pro, .proj)
The converted examples are available [here](https://github.com/FOSSEE/LTSpiceToKiCadConverter/tree/main/Examples/ConvertedKiCad_Schematics_no_eSim_Plots).

## Converted KiCad Schematics with eSim Simulation Plots
The Converted KiCad Schematics with eSim Simulation Plots are available [here](https://github.com/FOSSEE/LTSpiceToKiCadConverter/tree/main/Examples/ConvertedKiCadSchematics_witheSimPlots).

## Converted KiCad Symbol Library files(.lib)
The converted KiCad Symbol Library files are available [here](https://github.com/FOSSEE/LTSpiceToKiCadConverter/tree/main/Examples/ConvertedLibraries).

## Important Notes/Commands
**To change the access of the file and folder**

Use this command to change access to the files:</br>
	```
		chmod <options> <permissions> <file name>
	```</br> 
Example:</br>
	```
		chmod u=rwx,g=rx,o=r myfile
	```</br> 
You can also use:</br> 
	```	
		sudo chmod 777 filename.
	```</br> 
Example:</br>
	```
	sudo chmod 777 ~/Desktop/convert/rc
	```</br> 

-----------------------------------------------
**To open the KiCad schematic file in [eSim](https://esim.fossee.in/home)** 

1. Open eSim.
2. Create a *new project*.
3. Open the schematic using *open schematic* option.
4. Make sure all the libraries are loaded (9k+) using *Place component* option in eeschema.
5. Append the schematic using *Append Schematic* option from the file menu
6. Go to the directory where your files are converted.
7. Select the KiCad coverted schematic file (.sch). Click on Open.
8. To simulate, follow the instructions available on the eSim webpage.
-----------------------------------------------
**To load the KiCad libraries**

If all the libraries in eeschema are not loaded, follow these steps:
1. In eeschema, select *Preferences* option.
2. Click on the *Component Libraries* in the drop down list.
3. A dialog box appears, click on the *Add* option.
4. Go to the path where your library to be added is saved.
5. Select the library to be added and click on *Open* button.
6. Close the dialog box.
-----------------------------------------------

## Warning!
- All required libraries SHOULD be added.
- Use proper file format.
- DO NOT TRY TO CONVERT library file as schematic file or vice versa.
- Try adding libraries in the parser.py while getting error.
- DO NOT CHANGE any of the files unless and until needed.

## eSim Manual
To know everything about eSim, how it works and it's feature please download the manual from [here](https://static.fossee.in/esim/manuals/eSim_Manual_2.3.pdf)

## Contact
For any queries regarding eSim please write us on at this [email address](mailto:contact-esim@fossee.in).

## Contribution
Please refer [here](https://github.com/FOSSEE/eSim/blob/master/CONTRIBUTION.md) for further details.

# License
It is developed by FOSSEE Team at IIT Bombay and is released under GNU GPL License.

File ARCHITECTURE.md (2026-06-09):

# eSim Architecture & Workflows

This document contains detailed flowcharts and diagrams mapping out the inner workings, simulation pipelines, and data transformations within eSim.

---

## 1. Standard Simulation Workflow

This flowchart details the end-to-end user journey for a standard analog/digital simulation in eSim, from project creation to waveform analysis.

```mermaid
flowchart TD
    %% Styling
    classDef startend fill:#2ECC71,stroke:#27AE60,stroke-width:2px,color:#fff
    classDef process fill:#3498DB,stroke:#2980B9,stroke-width:2px,color:#fff
    classDef decision fill:#F1C40F,stroke:#F39C12,stroke-width:2px,color:#333
    classDef io fill:#9B59B6,stroke:#8E44AD,stroke-width:2px,color:#fff
    
    START([Start eSim Project]):::startend --> CREATE{New or Existing?}:::decision
    CREATE -- New --> PROJ[Create Project Structure]:::process
    CREATE -- Existing --> OPEN[Open Project Workspace]:::process
    
    PROJ --> SCHEM[Draw Schematic in KiCad]:::process
    OPEN --> SCHEM
    
    SCHEM --> CHECK{Mixed Signal?}:::decision
    CHECK -- Yes --> VHDL[Write VHDL/Verilog Models]:::process
    VHDL --> GHDL[Compile via NGHDL/NgVeri]:::process
    GHDL --> SYM[Generate KiCad Symbol]:::process
    SYM --> SCHEM
    
    CHECK -- No --> K2N[Run KiCad-to-Ngspice]:::process
    K2N --> PARSE[Parse XML Netlist]:::process
    PARSE --> SRC[Configure Sources & Analysis]:::process
    SRC --> DEV[Configure Device Models]:::process
    
    DEV --> SPICE[Generate .cir SPICE Netlist]:::io
    SPICE --> NGSPICE[Execute Ngspice Simulation]:::process
    
    NGSPICE --> OUT{Simulation Success?}:::decision
    OUT -- No --> ERR[View Error Log & Debug]:::process
    ERR --> SCHEM
    
    OUT -- Yes --> RAW[Generate RAW Output Data]:::io
    RAW --> PLOT[Extract Data for Plotting]:::process
    PLOT --> MAT[Render matplotlib Waveforms]:::process
    
    MAT --> END([Analyze Results]):::startend
```

---

## 2. Mixed-Signal Simulation Flow (NGHDL)

This diagram breaks down how eSim bridges digital logic (VHDL/Verilog) with analog simulation using GHDL and Ngspice code models.

```mermaid
flowchart TD
    %% Styling
    classDef input fill:#34495E,stroke:#2C3E50,stroke-width:2px,color:#fff
    classDef process fill:#16A085,stroke:#1ABC9C,stroke-width:2px,color:#fff
    classDef output fill:#8E44AD,stroke:#9B59B6,stroke-width:2px,color:#fff
    
    VHDL([Write VHDL/Verilog Code]):::input --> UPLOAD[Upload via NGHDL/NgVeri UI]:::process
    UPLOAD --> COMPILE[GHDL/Verilator Compiles Code to Shared Lib]:::process
    COMPILE --> MODEL[Create Ngspice Code Model .cm]:::process
    MODEL --> KICAD[Generate KiCad Component Symbol]:::output
    
    KICAD --> SCHEM([Place Symbol in Schematic]):::input
    SCHEM --> BRIDGE[ADC/DAC Bridge Insertion]:::process
    BRIDGE --> SIM[Execute Mixed-Signal Co-Simulation]:::output
```

---

## 3. KiCad-to-Ngspice Netlist Conversion

A deep dive into the `Convert.py` backend pipeline, showing how KiCad's XML data is processed into an executable SPICE netlist.

```mermaid
flowchart TD
    %% Styling
    classDef input fill:#34495E,stroke:#2C3E50,stroke-width:2px,color:#fff
    classDef process fill:#E67E22,stroke:#D35400,stroke-width:2px,color:#fff
    classDef io fill:#9B59B6,stroke:#8E44AD,stroke-width:2px,color:#fff
    
    XML([KiCad XML Netlist]):::input --> PARSE[Parse XML DOM]:::process
    PARSE --> EXTRACT[Extract Components & Connections]:::process
    EXTRACT --> MAP[Map Pins to Ngspice Nodes]:::process
    MAP --> SUB[Resolve Subcircuits & Macros]:::process
    SUB --> INJECT[Inject Device Parameters & Models]:::process
    INJECT --> SPICE([Generate .cir SPICE Netlist]):::io
```

---

## 4. Device Model Generation Pipeline

Outlining how user-defined models (Diodes, BJTs, MOSFETs) are integrated via the Model Editor.

```mermaid
flowchart LR
    %% Styling
    classDef input fill:#2C3E50,stroke:#1A252F,stroke-width:2px,color:#fff
    classDef process fill:#E74C3C,stroke:#C0392B,stroke-width:2px,color:#fff
    classDef output fill:#F39C12,stroke:#E67E22,stroke-width:2px,color:#fff
    
    UI([Model Editor UI]):::input --> VAL[Validate Parameters]:::process
    VAL --> TEMPLATE[Inject Data into SPICE Template]:::process
    TEMPLATE --> LIB([Save to project .lib file]):::output
    LIB --> K2N([Attached during Netlist Conversion]):::output
```

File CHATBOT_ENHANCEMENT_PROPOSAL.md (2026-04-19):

# eSim Copilot – Chatbot Enhancement Proposal

**Focus:** Hariom's approach (PR 434)  
**Branch:** Chatbot_Enhancements  
**Date:** March 2025

---

# Part 1: Document Summary

## 1.1 Four Source Documents

| Document | Author | Focus |
|---|---|---|
| **Project Context.pdf** | Synthesis | Rationale, problems, comparison of 3 interns, proposed Federated Knowledge Sync |
| **5 hariom.pdf** | Hariom Thakur | Full technical report: RAG, vision, FACT-based netlist, PyQt5 integration, automated error capture |
| **18 radhika goyal.pdf** | Radhika Goyal | Rule-based fault identification, static schematic/netlist analysis, cross-validation |
| **1 Nicholas_Coutinho.pdf** | Nicholas Coutinho | Conversational memory, topic discontinuity, context retention |

## 1.2 Three Intern Approaches (from Project Context)

| Aspect | Radhika | Nicholas | **Hariom** |
|---|---|---|---|
| **Intelligence** | Proactive static analysis, rule-based | Conversational memory, topic discontinuity | **FACT-based netlist, strict RAG grounding** |
| **UI Integration** | Standard chat | Standard chat | **Deep PyQt5: dock, toolbar, context menus, auto error capture** |
| **Multimodal** | Text + image | Text + image | **Text + image + voice (Vosk)** |
| **Tech stack** | Broad | Broad | **Specific: qwen2.5:3b, minicpm-v, nomic-embed-text, ChromaDB** |

**Project Context conclusion:** Hariom's approach is best for **practical deployment & user experience** due to deep integration, automated error capture, and voice STT.

---

# Part 2: Current Chatbot Functionality (Hariom's Implementation)

## 2.1 Architecture Overview

```
┌─────────────────────────────────────────────────────────────────────────┐
│  Presentation Layer (PyQt5)                                              │
│  • Application.py: toolbar, openChatbot(), errorDetectedSignal           │
│  • Chatbot.py: dock widget, chat UI, input, image/voice buttons           │
│  • ProjectExplorer.py: context menu "Analyze this Netlist"                │
│  • DockArea.py: createchatbotdock()                                       │
└─────────────────────────────────────────────────────────────────────────┘
                                    │
                                    ▼
┌─────────────────────────────────────────────────────────────────────────┐
│  Processing Layer (chatbot_core.py)                                       │
│  • classify_question_type() → routing                                     │
│  • handle_esim_question(), handle_image_query(), handle_netlist_analysis()│
│  • handle_follow_up(), handle_simple_question()                           │
└─────────────────────────────────────────────────────────────────────────┘
                                    │
                                    ▼
┌─────────────────────────────────────────────────────────────────────────┐
│  Data Layer                                                               │
│  • knowledge_base.py: ChromaDB, search_knowledge()                       │
│  • image_handler.py: PaddleOCR + MiniCPM-V                                │
│  • Chatbot.py: FACT-based netlist detection (_detect_floating_nodes, etc) │
│  • error_solutions.py: pattern → fixes mapping                           │
│  • ollama_runner.py: run_ollama(), run_ollama_vision(), get_embedding()   │
│  • stt_handler.py: Vosk offline STT                                       │
└─────────────────────────────────────────────────────────────────────────┘
```

## 2.2 Current Features (Implemented)

| Feature | Status | Location |
|---|---|---|
| **Intelligent Router** | ✅ | `chatbot_core.py` – classify_question_type() |
| **RAG (ChromaDB)** | ✅ | `knowledge_base.py` – search_knowledge() |
| **FACT-based netlist** | ✅ | `Chatbot.py` – _detect_floating_nodes, _detect_missing_models, etc. |
| **Vision (PaddleOCR + MiniCPM-V)** | ✅ | `image_handler.py` – analyze_and_extract() |
| **Voice (Vosk)** | ✅ (optional) | `stt_handler.py` |
| **Project Explorer context menu** | ✅ | `ProjectExplorer.py` – "Analyze this Netlist" |
| **Automated error capture** | ✅ | `Application.py` – errorDetectedSignal → send_error_to_chatbot |
| **Dockable chat** | ✅ | `Chatbot.py`, `DockArea.py` |
| **Error pattern matching** | ✅ | `error_solutions.py` – ERROR_SOLUTIONS dict |

## 2.3 Current Gaps / Limitations (from Hariom's report)

1. **Model capability constraints:** qwen2.5:3b struggles with complex multi-step reasoning; minicpm-v misinterprets complex topologies; 2048-token context limit.
2. **Performance on low-end hardware:** 8GB RAM minimum; vision can take 10+ seconds on older CPUs.
3. **Scope limitations:** No training mode; fixed knowledge base; cannot dynamically add new docs.
4. **PaddleOCR:** Often fails on first run (no `paddle` module) – vision falls back to partial OCR.
5. **Netlist contract:** Missing `manuals/esim_netlist_analysis_output_contract.txt` in some setups.

---

# Part 3: Proposed Enhancements (Hariom’s Approach)

## 3.1 Near-Term (Next 6 Months) – from Hariom's report

### 3.1.1 One-Click Netlist Fix

**Current:** Copilot suggests fixes; user must manually edit in Spice Editor.

**Proposal:** Add "Apply fix" button that auto-inserts suggested fixes into `.cir.out`:

- Add missing `.model` statements
- Add `.options gmin=1e-12 reltol=0.01` for singular matrix
- Add 1G resistors for floating nodes (as comments with copy-paste snippet)

**Implementation:** Extend `Chatbot.py` – parse FACT output, generate patch, offer "Insert into netlist" action.

---

### 3.1.2 Real-Time Suggestions in KiCad

**Current:** User must open Copilot and ask.

**Proposal:** Optional "live hints" during schematic capture – e.g. when floating pin detected, show small tooltip: "R1 pin 2 is unconnected."

**Implementation:** Requires KiCad callback or periodic checks; may need eSim/KiCad integration points.

---

### 3.1.3 Batch Processing for Multiple Images/Netlists

**Current:** One image or netlist at a time.

**Proposal:** Allow selecting multiple `.cir.out` files or pasting multiple images; run analysis in batch; report summary.

**Implementation:** Extend `Chatbot.py` – `analyze_specific_netlist()` accepts list; `handle_image_query()` can process multiple paths.

---

### 3.1.4 RAG Relevance Threshold

**Current:** `knowledge_base.py` returns top 4 chunks; no explicit cosine similarity filter.

**Proposal:** Add relevance threshold (e.g. cosine similarity > 0.3) – Hariom's report mentions this; filter out low-similarity chunks to reduce hallucination.

**Implementation:** ChromaDB query returns `distances`; filter by threshold before context assembly.

---

### 3.1.5 Stricter FACT-Based Prompting

**Current:** Netlist analysis uses FACT blocks; contract file may be missing.

**Proposal:** Ensure contract is always available; bundle `esim_netlist_analysis_output_contract.txt` in repo; add fallback inline prompt if file missing.

**Implementation:** Copy contract to `src/manuals/` or `src/frontEnd/manuals/`; ensure `Chatbot.py` loads from correct path.

---

### 3.1.6 Model Selection (Optional)

**Current:** Hardcoded qwen2.5:3b, minicpm-v.

**Proposal:** Allow user to choose model in settings (e.g. llama3, deepseek-coder for code-heavy tasks).

**Implementation:** Add `ollama_model` config; pass to `run_ollama()`.

---

## 3.2 Medium-Term (6–18 Months)

### 3.2.1 Circuit Optimization Suggestions

**Proposal:** After simulation succeeds, analyze output and suggest improvements (e.g. "Add capacitor for stability").

**Implementation:** Parse `.raw` or simulation output; integrate with plotting tools; add optional "optimization" analysis mode.

---

### 3.2.2 Predictive Error Detection During Schematic Capture

**Proposal:** (Radhika's strength) – cross-validate schematic vs netlist before simulation; detect mismatches early.

**Implementation:** Hook into eSim's netlist generation; run static analysis on generated netlist before user runs simulation.

---

### 3.2.3 Enhanced Conversation Memory (Nicholas's strength)

**Proposal:** Improve topic discontinuity detection; add reference resolution for "this", "that", "it".

**Implementation:** Refine `_is_follow_up_question()` and `is_semantic_topic_switch()`; use embedding similarity for pronoun resolution.

---

### 3.2.4 Federated Knowledge Sync (Project Context proposal)

**Proposal:** When user fixes an error after Copilot failed, prompt: "What did you change?" – store locally; optionally sync anonymously to FOSSEE server; server clusters fixes; push updates to ChromaDB.

**Implementation:** Large; requires server, encryption, consent UI. Defer to long-term.

---

## 3.3 Long-Term (18+ Months)

- **Autonomous design assistance:** Circuit synthesis from specs.

- **Research platform:** Dataset from anonymized interactions; benchmarking suite.

- **Ecosystem expansion:** Port to OpenModelica, Scilab; plugin architecture.

---

# Part 4: Prioritized Implementation Roadmap

| Priority | Enhancement | Effort | Impact |
|---|---|---|---|
| 1 | RAG relevance threshold | Low | High (reduces hallucination) |
| 2 | Netlist contract bundling | Low | Medium (fixes missing contract) |
| 3 | One-click netlist fix | Medium | High (UX) |
| 4 | Batch netlist analysis | Low | Medium |
| 5 | Model selection in settings | Low | Medium |
| 6 | Enhanced conversation memory | Medium | Medium |
| 7 | Batch image processing | Low | Low |
| 8 | Real-time KiCad hints | High | Medium |

---

# Part 5: Quick Wins (Immediate)

1. **Add relevance threshold to `search_knowledge()`** – filter by distance/similarity.
2. **Bundle netlist contract** – ensure `esim_netlist_analysis_output_contract.txt` is in `src/manuals/` or `src/frontEnd/manuals/` and loaded correctly.
3. **Improve error message clarity** – when PaddleOCR fails, show: "Vision analysis unavailable. Text and netlist analysis still work."
4. **Add "Copy to clipboard" for netlist fixes** – so user can paste without manual retyping.

---

# Part 6: File Reference

| File | Purpose |
|---|---|
| `src/chatbot/chatbot_core.py` | Router, handlers, classification |
| `src/chatbot/knowledge_base.py` | ChromaDB, search_knowledge |
| `src/chatbot/ollama_runner.py` | Ollama API, embeddings |
| `src/chatbot/image_handler.py` | PaddleOCR, MiniCPM-V |
| `src/chatbot/stt_handler.py` | Vosk STT |
| `src/chatbot/error_solutions.py` | Error pattern → fixes |
| `src/frontEnd/Chatbot.py` | UI, netlist FACT detection, analyze_specific_netlist |
| `src/frontEnd/Application.py` | errorDetectedSignal, openChatbot |
| `src/frontEnd/ProjectExplorer.py` | Context menu |

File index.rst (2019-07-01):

.. eSim documentation master file, created by
   sphinx-quickstart on Mon Jun 10 19:26:41 2019.
   You can adapt this file completely to your liking, but it should at least
   contain the root `toctree` directive.

Welcome to eSim's documentation!
================================

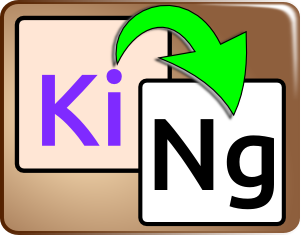
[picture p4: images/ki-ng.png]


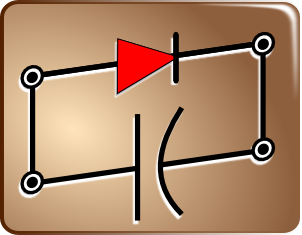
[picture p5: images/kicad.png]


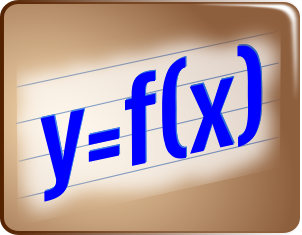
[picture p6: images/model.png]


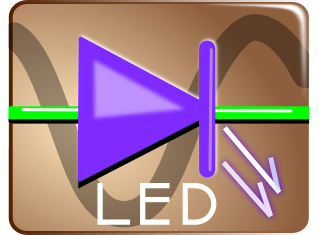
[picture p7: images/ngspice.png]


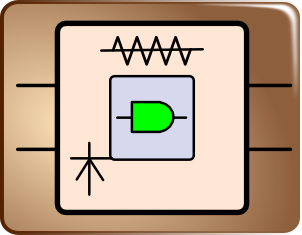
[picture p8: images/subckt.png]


.. toctree::
   :maxdepth: 3
   :caption: Contents:

   code/configuration
   code/browser
   code/frontEnd
   code/kicadtoNgspice
   code/ngspiceSimulation
   code/projectManagement
   code/modelEditor
   code/subcircuit

Indices and tables
==================

* :ref:`genindex`
* :ref:`modindex`
* :ref:`search`

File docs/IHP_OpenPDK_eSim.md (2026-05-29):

# Integration of IHP OpenPDK with eSim

## Overview

This contribution demonstrates the integration of the IHP OpenPDK with eSim
to enable CMOS circuit design and simulation using open-source EDA tools.

## Objective

- Integrate IHP OpenPDK MOSFET SPICE models with eSim
- Design and simulate a CMOS inverter
- Perform DC sweep and transient analysis
- Validate inverter switching behavior

## Tools Used

- eSim (KiCad + NgSpice)
- IHP OpenPDK
- NgSpice

## Circuit Implemented

- CMOS Inverter using IHP NMOS and PMOS models
- Supply voltage: 1.8V

## Simulations Performed

### Transient Analysis

- `.tran 0.1ns 20ns`
- Verified correct logical inversion

### DC Sweep Analysis

- `.dc VIN 0 1.8 0.01`
- Verified voltage transfer characteristics

## Results

- Correct inverter operation observed
- Threshold voltage near mid-supply
- Stable transient and DC behavior

## Notes

- Absolute paths were used for SPICE model inclusion
- Convergence issues resolved by reducing timestep

## Report and Demo

The detailed report and demonstration video are provided via links
in the corresponding GitHub Pull Request.

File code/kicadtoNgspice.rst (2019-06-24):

kicadtoNgspice Component
========================

.. toctree::
	:maxdepth: 2
	:caption: Contents:

	kicadtoNgspice/Analysis
	kicadtoNgspice/Convert
	kicadtoNgspice/DeviceModel
	kicadtoNgspice/KicadtoNgspice
	kicadtoNgspice/Model
	kicadtoNgspice/Processing
	kicadtoNgspice/Source
	kicadtoNgspice/SubcircuitTab
	kicadtoNgspice/TrackWidget

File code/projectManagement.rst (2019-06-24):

Project Management Component
============================

.. toctree::
	:maxdepth: 2
	:caption: Contents:

	projectManagement/Kicad
	projectManagement/Validation
	projectManagement/Worker
	projectManagement/openProject
	projectManagement/newProject

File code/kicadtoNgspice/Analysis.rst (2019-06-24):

Analysis Component
==================

.. automodule:: kicadtoNgspice.Analysis
	:members:

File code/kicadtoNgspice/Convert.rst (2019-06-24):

Convert Component
=================

.. automodule:: kicadtoNgspice.Convert
	:members:

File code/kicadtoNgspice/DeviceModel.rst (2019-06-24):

Device Model Component
======================

.. automodule:: kicadtoNgspice.DeviceModel
	:members:

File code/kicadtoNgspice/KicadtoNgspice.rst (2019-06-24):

KicadtoNgspice component
========================

.. automodule:: kicadtoNgspice.KicadtoNgspice
	:members:

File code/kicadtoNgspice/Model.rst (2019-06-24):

Model Component
===============

.. automodule:: kicadtoNgspice.Model
	:members:

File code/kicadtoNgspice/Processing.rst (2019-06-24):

Processing Component
====================

.. automodule:: kicadtoNgspice.Processing
	:members:

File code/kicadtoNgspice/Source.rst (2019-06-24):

Source Component
================

.. automodule:: kicadtoNgspice.Source
	:members:

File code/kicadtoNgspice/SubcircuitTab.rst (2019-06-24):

Subcircuit Tab component
========================

.. automodule:: kicadtoNgspice.SubcircuitTab
	:members:

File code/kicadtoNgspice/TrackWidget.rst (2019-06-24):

Track Widget Component
======================

.. automodule:: kicadtoNgspice.TrackWidget
	:members:

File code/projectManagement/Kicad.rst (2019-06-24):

Open Kicad Schematic Button
===========================

.. automodule:: projManagement.Kicad
	:members:

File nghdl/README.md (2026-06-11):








Ngspice Ghdl Interfacing Documentation 
====

It contains all the documentation for Ngspice and GHDL related work.

## How is Ngspice interfaced with GHDL?
Ngspice supports mixed-signal simulation. It can simulate both digital and analog components.

Ngspice has something called code-model which defines the behavior of your component and can be used in the netlist. For example you can create a full-adder's code-model in Ngspice and use it in any circuit netlist of Ngspice.

Now the question is if we already have digital model creation in Ngspice, then why this interfacing?

Well, in Ngspice, it is difficult to write your own digital code-models. Though, many people are familiar with GHDL and can easily write the VHDL code.
So the idea of interfacing is just to write VHDL code for a model and use it as a dummy model in Ngspice. Thus, whenever Ngspice looks for that model, it will actually call GHDL to get the results.
GHDL's foreign language interface is used for this inter-process communication.

## Releases
* Ubuntu 18.04 and 20.04 LTS versions.
* Microsoft Windows 7, 8 and 10.

    > Note for other distributions: You can refer [`installers`](https://github.com/fossee/nghdl/tree/installers) branch for documentation on packaging (for above mentioned distributions) to build installers for your operating system in a similar way. For providing your build, please check the `Contribution` section mentioned below.

## Features
* Support for nearly 500 VHDL digital models.
* Support for VHDL digital models upto 64 output ports/pins.
* Support for Verilog digital models.

## Pre-requisites
* [GHDL (LLVM - v0.37)](http://ghdl.free.fr/)
* [Verilator (v4.210)](https://www.veripool.org/verilator/)
* [Ngspice (v35+)](https://ngspice.sourceforge.io/)

## How to install?
This module is made available with eSim (Electronic Circuit Simulation). 
Refer https://esim.fossee.in/ for more information.

## How to use the Examples provided with NGHDL?
1. Launch eSim --> Click on "NGHDL" icon from the left toolbar --> Click on "Browse" button --> Go to `nghdl/Example/`
2. Locate the example you wish to simulate, find the VHDL file within that example and click on "Open" button at the bottom of "Open File" window.
3. Click on "Upload" button in the NGHDL window. File will be processed in the backend for few seconds. Now exit the NGHDL window.
4. Open the desired example under `eSim/Examples/Mixed_Signal/` using the "Open Project" button, double click on the project when the project is loaded in the "Projects" window.
5. Click on the "Simulation" button on eSim Main window.

## Microwatt Example

A Microwatt OpenPOWER NGHDL co-simulation example is available under:

`nghdl/Example/Microwatt`

This example demonstrates the integration of the OpenPOWER Microwatt core with the NGHDL/XSPICE co-simulation flow in eSim. The example includes:

* `microwatt_cosim.vhdl` - NGHDL-compatible Microwatt wrapper
* `compile_for_nghdl.sh` - GHDL compilation script for NGHDL
* `README.md` - Usage and integration instructions

## Contribution
Please refer [here](https://github.com/FOSSEE/nghdl/blob/master/CONTRIBUTION.md) for further details.

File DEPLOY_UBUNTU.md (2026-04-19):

# Deploy eSim Copilot on Ubuntu (VM or WSL2)

Use this guide for **first-time deployment** of the AI chatbot on a Linux environment.

---

## VM setup checklist (Option A)

| Step | Action |
|---|---|
| 1 | Download [Ubuntu 22.04 Desktop](https://ubuntu.com/download/desktop) ISO |
| 2 | Create VM (VirtualBox/Hyper-V/VMware): 4–8 GB RAM, 25 GB disk |
| 3 | Install Ubuntu in VM, install Guest Additions (VirtualBox) if using shared folder |
| 4 | Copy eSim into VM (shared folder or zip) → `~/work/eSim` |
| 5 | Run `./scripts/setup_copilot_ubuntu.sh` |
| 6 | Start `ollama serve` in a second terminal |
| 7 | Run `python ingest.py` (optional) |
| 8 | Launch: `QT_QPA_PLATFORM=xcb python Application.py` from `src/frontEnd` |

---

## Option A: Ubuntu VM (recommended for full GUI)

### 1. Create Ubuntu VM

#### 1a. Download Ubuntu 22.04 Desktop

- Go to [ubuntu.com/download/desktop](https://ubuntu.com/download/desktop)
- Download **Ubuntu 22.04 LTS** (64-bit, ~4 GB ISO)

#### 1b. Choose your hypervisor

| Tool | Steps |
|---|---|
| **VirtualBox** (free) | 1. Install [VirtualBox](https://www.virtualbox.org/wiki/Downloads)<br>2. New VM → Name: `eSim-Ubuntu`, Type: Linux, Version: Ubuntu (64-bit)<br>3. RAM: **4096 MB** (minimum), **8192 MB** recommended for Ollama<br>4. Create virtual disk: **VDI**, **Dynamically allocated**, **25 GB**<br>5. Settings → Storage → Empty → Choose Ubuntu ISO<br>6. Start VM → Install Ubuntu (normal install, minimal if offered) |
| **Hyper-V** (Windows Pro) | 1. Enable Hyper-V: `OptionalFeatures` → check Hyper-V<br>2. Hyper-V Manager → New → Virtual Machine<br>3. Generation 2, 4096 MB RAM, 25 GB disk<br>4. Connect to Ubuntu ISO, boot and install |
| **VMware Workstation** | Same as VirtualBox: New VM → Typical → Ubuntu ISO → 4 GB RAM, 25 GB disk |

**Important:** Allocate at least **4 GB RAM**; 8 GB is better if you run Ollama models inside the VM.

---

### 2. Get the code into Ubuntu

#### Option 2a – Copy from Windows (shared folder or zip)

**Using VirtualBox shared folder:**

1. In VirtualBox: VM Settings → Shared Folders → Add
2. Folder path: `C:\Users\91900\Downloads\eSIM-Software-AIChatBot\repos`
3. Folder name: `repos` (or `esim_repo`)
4. Check **Auto-mount**, **Make permanent**
5. Inside Ubuntu VM, install Guest Additions (Devices → Insert Guest Additions CD, then run it)
6. Add your user to `vboxsf`: `sudo usermod -aG vboxsf $USER` → log out and back in
7. Copy eSim into your home:
   ```bash
   mkdir -p ~/work
   cp -r /media/sf_repos/eSim ~/work/eSim
   cd ~/work/eSim
   git checkout Chatbot_Enhancements
   ```

**Using zip (no shared folder):**

1. On Windows, zip the folder:
   - Right-click `repos\eSim` → Send to → Compressed folder
   - Or in PowerShell (from workspace root): `.\repos\eSim\scripts\zip_for_vm.ps1` → creates `eSim-for-VM.zip`
2. Copy `eSim-for-VM.zip` into the VM (drag-drop, USB, or network share)
3. Inside Ubuntu:
   ```bash
   mkdir -p ~/work && cd ~/work
   unzip /path/to/eSim-for-VM.zip   # e.g. unzip ~/Downloads/eSim-for-VM.zip
   cd eSim
   git checkout Chatbot_Enhancements
   ```

#### Option 2b – Clone from GitHub (if Chatbot_Enhancements is on your fork)

```bash
sudo apt update && sudo apt install -y git
mkdir -p ~/work && cd ~/work
git clone https://github.com/FOSSEE/eSim.git
cd eSim
git fetch origin pull/434/head:pr-434
git checkout -b Chatbot_Enhancements pr-434
# If you pushed Chatbot_Enhancements to your fork:
# git remote add myfork https://github.com/YOUR_USER/eSim.git
# git fetch myfork Chatbot_Enhancements
# git checkout Chatbot_Enhancements
```

---

### 3. Run one-command setup

```bash
cd ~/work/eSim
chmod +x scripts/setup_copilot_ubuntu.sh
./scripts/setup_copilot_ubuntu.sh
```

This installs system packages, Python venv, Ollama, models (qwen2.5:3b, minicpm-v, nomic-embed-text), and Vosk. It may take 15–30 minutes depending on your connection.

---

### 4. Start Ollama (keep running in a separate terminal)

Open a **new terminal** and run:

```bash
ollama serve
```

Leave this running. The Copilot needs Ollama to answer questions.

---

### 5. Ingest manuals for RAG (optional but recommended)

```bash
cd ~/work/eSim
source .venv/bin/activate
cd src
python ingest.py
```

Add `.txt` manuals to `src/manuals/` first if you have them; otherwise ingest may find nothing (RAG will still work, but with less context).

---

### 6. Launch eSim with Copilot

```bash
cd ~/work/eSim
source .venv/bin/activate
cd src/frontEnd
QT_QPA_PLATFORM=xcb python Application.py
```

Click the **eSim Copilot** button in the toolbar to open the AI chat.

---

### Quick copy-paste (after VM is ready and code is in ~/work/eSim)

```bash
cd ~/work/eSim && git checkout Chatbot_Enhancements
chmod +x scripts/setup_copilot_ubuntu.sh && ./scripts/setup_copilot_ubuntu.sh
# When done: open a second terminal and run: ollama serve
# Then in first terminal:
source .venv/bin/activate && cd src && python ingest.py
cd ~/work/eSim && source .venv/bin/activate && cd src/frontEnd && QT_QPA_PLATFORM=xcb python Application.py
```

---

## Option B: WSL2 (Windows Subsystem for Linux)

### 1. Install WSL2 + Ubuntu

In **PowerShell (Admin)**:

```powershell
wsl --install
wsl --set-default-version 2
wsl --install -d Ubuntu-22.04
```

Reboot if prompted, then open **Ubuntu 22.04** from Start.

### 2. Follow steps 2–5 from Option A

All commands are the same inside the Ubuntu terminal.

---

## Troubleshooting

| Issue | Fix |
|---|-----|
| "Ollama not responding" | Run `ollama serve` in a separate terminal before launching eSim |
| GUI doesn't appear (WSL) | Ensure you use the Ubuntu app (not SSH). WSLg provides display automatically |
| Voice input fails | Microphone passthrough in WSL can be unreliable; text + image + netlist still work |
| `python ingest.py` finds no files | Add `.txt` manuals to `src/manuals/` before running ingest |

---

## Branch: Chatbot_Enhancements

This deployment uses the `Chatbot_Enhancements` branch, based on Hariom's PR 434, with:

- Seamless install script for Ubuntu
- User-writable ChromaDB path
- Optional speech-to-text (graceful fallback if Vosk missing)
- Split requirements (base + copilot)

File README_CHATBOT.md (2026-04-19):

# eSim Copilot – AI-Assisted Electronics Simulation Tool

eSim Copilot is an AI-powered assistant integrated into **eSim**, designed to help users analyze electronic circuits, debug SPICE netlists, understand simulation errors, and interact using text, voice, and images.

This project combines **PyQt5**, **ngspice**, **Ollama (LLMs)**, **RAG (ChromaDB)**, **OCR**, and **offline speech-to-text** into a single desktop application.

**→ First-time deployment on Ubuntu (VM or WSL2): see [DEPLOY_UBUNTU.md](DEPLOY_UBUNTU.md)**

---

## Key Features

-  AI assistant for electronics & eSim
-  Netlist analysis and error explanation
-  ngspice simulation integration
-  Circuit image analysis (OCR + vision models)
-  Offline speech-to-text (no internet required)
-  Knowledge base using RAG (manuals + docs)
-  Fully offline-capable (except model downloads)

## Supported Platform

- **Linux only** (Recommended: Ubuntu 22.04 / 23.04 / 24.04)
- Tested on **Ubuntu 22.04 & 24.04**

---

## Python Version (VERY IMPORTANT)

## Supported
- **Python 3.9 – 3.10 (RECOMMENDED)**

Check version:
```bash
python --version

## System Dependencies (Install First)
```bash

sudo apt update
sudo apt upgrade

sudo apt update
sudo apt install -y \
  libxcb-xinerama0 \
  libxcb-cursor0 \
  libxkbcommon-x11-0 \
  libxcb-icccm4 \
  libxcb-image0 \
  libxcb-keysyms1 \
  libxcb-render-util0 \
  libxcb-xinput0 \
  libxcb-shape0 \
  libxcb-randr0 \
  libxcb-util1 \
  libgl1 \
  libglib2.0-0

## Clone the Repository

git clone <https://github.com/HARIOM-BEEP/eSim>
cd eSim-master

## Ollama (LLM Backend)
```bash

curl -fsSL https://ollama.com/install.sh | sh
ollama serve
ollama pull qwen2.5:3b
ollama pull minicpm-v
ollama pull nomic-embed-text

## Offline Speech-to-Text (VOSK)
```bash

mkdir -p ~/vosk-models
cd ~/vosk-models
wget https://alphacephei.com/vosk/models/vosk-model-small-en-us-0.15.zip
unzip vosk-model-small-en-us-0.15.zip

export VOSK_MODEL_PATH=~/vosk-models/vosk-model-small-en-us-0.15

echo 'export VOSK_MODEL_PATH=~/vosk-models/vosk-model-small-en-us-0.15' >> ~/.bashrc
source ~/.bashrc

## Python Virtual Environment (Recommended)
```bash

python3.10 -m venv venv
source venv/bin/activate
pip uninstall -y pip
python -m ensurepip
python -m pip install pip==22.3.1
python -m pip install setuptools==65.5.0 wheel==0.38.4

python -m pip install hdlparse==1.0.4 --no-build-isolation

pip install -r requirements.txt

pip install paddlepaddle==2.5.2 \
  -f https://www.paddlepaddle.org.cn/whl/linux/mkl/avx/stable.html

pip uninstall -y opencv-python opencv-contrib-python opencv-python-headless
pip install opencv-python-headless==4.6.0.66

## Before running eSim

unset QT_PLUGIN_PATH
export QT_QPA_PLATFORM=xcb

## Ingest manuals for RAG 
```bash
cd src
python ingest.py

## Running the Application
```bash
cd src/frontEnd
python Application.py

## Common Warnings (Safe to Ignore)

PaddleOCR init failed: show_log
QSocketNotifier: Can only be used with threads started with QThread
libpng iCCP: incorrect sRGB profile
PyQt sipPyTypeDict() deprecation warnings

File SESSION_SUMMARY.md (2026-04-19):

# eSim Copilot Deployment – Complete Guide

**Date:** March 3, 2025  
**Branch:** `Chatbot_Enhancements` (from `pr-434`)  
**Goal:** First deployment of eSim AI Copilot on Ubuntu VM

This document explains every step, every file, every command, and every fix from this deployment session.

---

# Table of Contents

1. [Project Overview](#1-project-overview)
2. [Branch Setup](#2-branch-setup)
3. [Branch Changes & Commit History](#3-branch-changes--commit-history)
4. [Technical Breakdown of Fixes](#4-technical-breakdown-of-fixes)
5. [Ubuntu VM Setup](#5-ubuntu-vm-setup)
6. [Networking & SSH](#6-networking--ssh)
7. [Code Transfer to VM](#7-code-transfer-to-vm)
8. [Setup Script – Full 7-Step Flow](#8-setup-script--full-7-step-flow)
9. [Ollama & Models](#9-ollama--models)
10. [Launch & Usage](#10-launch--usage)
11. [Known Issues & Troubleshooting](#11-known-issues--troubleshooting)
12. [Push to GitHub](#12-push-to-github)

---

# 1. Project Overview

## What is eSim?
**eSim** is an open-source electronics simulation tool (FOSSEE/eSim) that uses:
- **ngspice** – SPICE circuit simulator
- **KiCad** – Schematic capture
- **PyQt5** – Desktop GUI

## What is eSim Copilot?
Enhanced assistant integrated into eSim, providing:
- **Text chat:** Ollama (LLM)
- **RAG:** ChromaDB
- **Vision:** PaddleOCR, MiniCPM-V
- **Speech-to-text:** Vosk

---

# 2. Branch Setup

```bash
# Created from Hariom's Copilot implementation
git fetch origin pull/434/head:pr-434
git checkout -b Chatbot_Enhancements pr-434
```

---

# 3. Branch Changes & Commit History

### Key File Changes
- **`scripts/setup_copilot_ubuntu.sh`**: New comprehensive setup script.
- **`scripts/launch_esim.sh`**: New utility to launch with correct Qt backend.
- **`src/frontEnd/Workspace.py`**: Fixed directory creation bug.
- **`src/chatbot/stt_handler.py`**: Made STT optional with graceful fallback.
- **`.gitattributes`**: Added to force LF on shell scripts.

### Recent Commits
- `71ed0f5c`: SESSION_SUMMARY: comprehensive guide with every item explained
- `4c67304d`: Ubuntu deployment, hdlparse fix, Workspace.py fix, launch script
- `67f08043`: Ubuntu deployment support, optional STT, ChromaDB path fix

---

# 4. Technical Breakdown of Fixes

### 4.1 hdlparse & setuptools Fix
**Problem:** `hdlparse==1.0.4` uses `use_2to3`, which was removed in `setuptools 58+`.
**Fix:** 
1. Manually install `setuptools==57.5.0`.
2. Install `hdlparse` with `--no-build-isolation` to force it to use the downgrade.
3. Use a `/tmp/pip-constraints.txt` with `setuptools<58` for all subsequent installs.

### 4.2 Workspace.py Crash
**Problem:** `FileNotFoundError` when writing `~/.esim/workspace.txt` because the `.esim` folder was missing.
**Fix:** Added `os.makedirs(esim_dir, exist_ok=True)` in `src/frontEnd/Workspace.py`.

### 4.3 Mandatory LF for Scripts
**Problem:** `bash\r: No such file or directory` due to Windows CRLF.
**Fix:** Created `.gitattributes` to enforce `*.sh text eol=lf`.

### 4.4 Graceful STT Fallback
**Problem:** App crashed if `vosk` or `sounddevice` were missing.
**Fix:** Wrapped imports in `try/except` and added `_HAS_STT` flag in `stt_handler.py`.

---

# 5. Ubuntu VM Setup
- **ISO:** Ubuntu 22.04 LTS
- **Hardware:** 4-8 GB RAM, 25 GB Disk
- **Network:** Bridged Adapter (preferred) or NAT with Port Forwarding (2222 -> 22)

---

# 6. Networking & SSH
```bash
sudo apt install -y openssh-server
sudo systemctl enable --now ssh
ip addr # Find IP
```

---

# 7. Code Transfer to VM
- **Method A (SCP):** `scp -r repos/eSim user@ip:~/work/`
- **Method B (Zip):** Use `./scripts/zip_for_vm.ps1` on Windows, then transfer zip.

---

# 8. Setup Script – Full 7-Step Flow
Run `./scripts/setup_copilot_ubuntu.sh`:
1. **System Packages:** Install `ngspice`, `kicad`, `portaudio`, `libxcb` (Qt dependencies).
2. **Virtualenv:** Create isolated `.venv`.
3. **Python Deps:** Pip upgrade, `setuptools` downgrade, and RAG/AI requirements.
4. **PaddlePaddle:** Install CPU version for OCR.
5. **Ollama:** Download and install LLM server.
6. **Models:** Pull `qwen2.5:3b`, `minicpm-v`, and `nomic-embed-text`.
7. **Vosk:** Download offline English model to `~/.local/share/esim-copilot/`.

---

# 9. Ollama & Models
- **API:** `http://127.0.0.1:11434`
- **Service:** Managed via `systemctl` or manual `ollama serve`.

---

# 10. Launch & Usage
```bash
./scripts/launch_esim.sh
```
*Note: Uses `QT_QPA_PLATFORM=xcb` for compatibility over SSH X11 forwarding.*

---

# 11. Known Issues & Troubleshooting
| Issue | Fix |
|---|---|
| `bash\r` | `sed -i 's/\r$//' scripts/setup_copilot_ubuntu.sh` |
| `hdlparse` error | Ensure `setuptools<58` is used. |
| No GUI | Enable X11 forwarding in MobaXterm. |

---

# 12. Push to GitHub
1. Fork `FOSSEE/eSim` on GitHub.
2. `git remote add myfork https://github.com/YOUR_USER/eSim.git`
3. `git push myfork Chatbot_Enhancements`

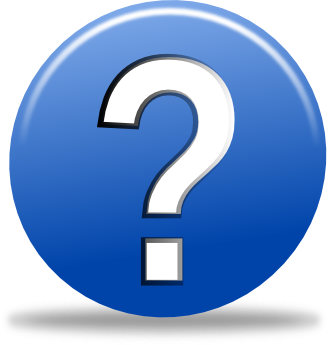
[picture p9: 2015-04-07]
images/helpProject.png

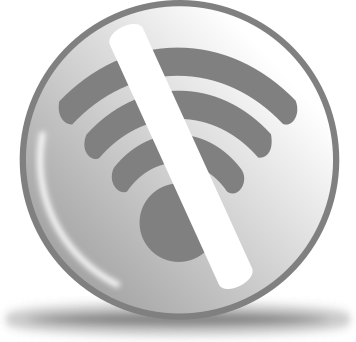
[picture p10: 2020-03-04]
images/disable.png

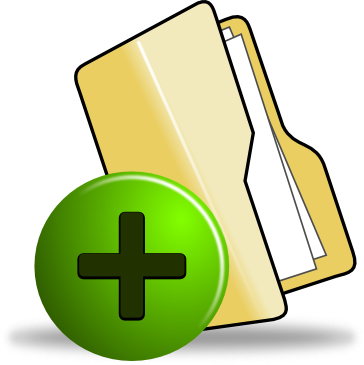
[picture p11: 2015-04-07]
images/newProject.png

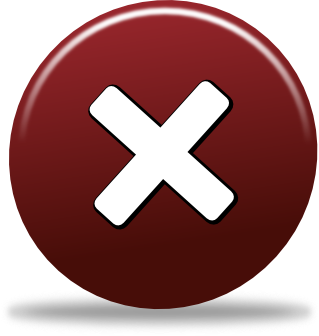
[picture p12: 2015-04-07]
images/closeProject.png

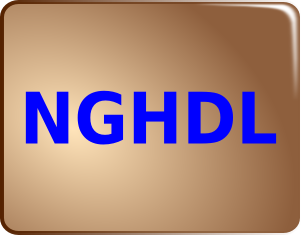
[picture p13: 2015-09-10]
images/nghdl.png

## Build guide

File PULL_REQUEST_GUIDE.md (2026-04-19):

# Pull Request Guide – eSim RAGbot Enhancements

## 1. Git Configuration (Done ✓)

- **Email:** `harvi.bhavinpatel2024@vitstudent.ac.in`
- **Name:** `Harvi-2215`

## 2. Create Your Fork on GitHub

If you don't have a fork yet:

1. Go to **[https://github.com/FOSSEE/eSim](https://github.com/FOSSEE/eSim)**
2. Click **Fork** (top right)
3. Choose your account (ensure you're logged in as the account for `harvi.bhavinpatel2024@vitstudent.ac.in`)
4. The fork will be created at `https://github.com/YOUR_USERNAME/eSim`

**Note:** Your GitHub username may be `Harvi-2215` or `HraviPatel` – use whichever matches your account.

## 3. Add Your Fork as Remote (if needed)

```powershell
cd C:\Users\91900\Downloads\eSIM-Software-AIChatBot\repos\eSim

# If using Harvi-2215:
git remote add harvi-fork https://github.com/Harvi-2215/eSim.git

# OR if using HraviPatel (already exists as hravipatel):
# git remote add hravipatel https://github.com/HraviPatel/eSim.git
```

## 4. Push Your Branch to the Fork

```powershell
cd C:\Users\91900\Downloads\eSIM-Software-AIChatBot\repos\eSim

# Push to Harvi-2215 fork:
git push harvi-fork esim-RAGbot-enhacements:esim-RAGbot-Enhacements-Harvi

# OR push to HraviPatel fork:
git push hravipatel esim-RAGbot-enhacements:esim-RAGbot-Enhacements-Harvi
```

When prompted, sign in with `harvi.bhavinpatel2024@vitstudent.ac.in` (or your GitHub credentials).

## 5. Create the Pull Request

1. Open your fork: `https://github.com/YOUR_USERNAME/eSim`
2. You should see a banner: **"esim-RAGbot-Enhacements-Harvi had recent pushes"** with a **Compare & pull request** button
3. Click **Compare & pull request**
4. Set:
   - **Base repository:** `FOSSEE/eSim`
   - **Base branch:** `master` (or `main` if that's the default)
   - **Head repository:** `YOUR_USERNAME/eSim`
   - **Compare branch:** `esim-RAGbot-Enhacements-Harvi`
5. Add a title, e.g. **"Copilot enhancements: RAG threshold, netlist contract, PaddleOCR, copy button"**
6. Add a description of the changes
7. Click **Create pull request**

## 6. Changes Included in This Branch

| File | Change |
|---|---|
| `.gitignore` | Added `scripts/deploy_to_vm.ps1` |
| `scripts/launch_esim.sh` | Vosk model path auto-detection |
| `src/chatbot/image_handler.py` | PaddleOCR error message |
| `src/chatbot/knowledge_base.py` | RAG relevance threshold |
| `src/frontEnd/Chatbot.py` | Netlist contract bundling, copy-to-clipboard |
| `scripts/README_TESTS.md` | Test instructions and deploy steps |
| `scripts/deploy_to_vm.ps1.example` | Deploy script template |
| `scripts/test_copilot_enhancements.py` | Enhancement tests |
| `scripts/test_copilot_enhancements.sh` | Shell wrapper for tests |

## Troubleshooting

| Issue | Fix |
|---|-----|
| Push asks for credentials | Use GitHub CLI (`gh auth login`) or Git Credential Manager |
| "Repository not found" | Create the fork on GitHub first (Step 2) |
| Wrong GitHub account | Check `git config user.email` and ensure it matches your GitHub email |

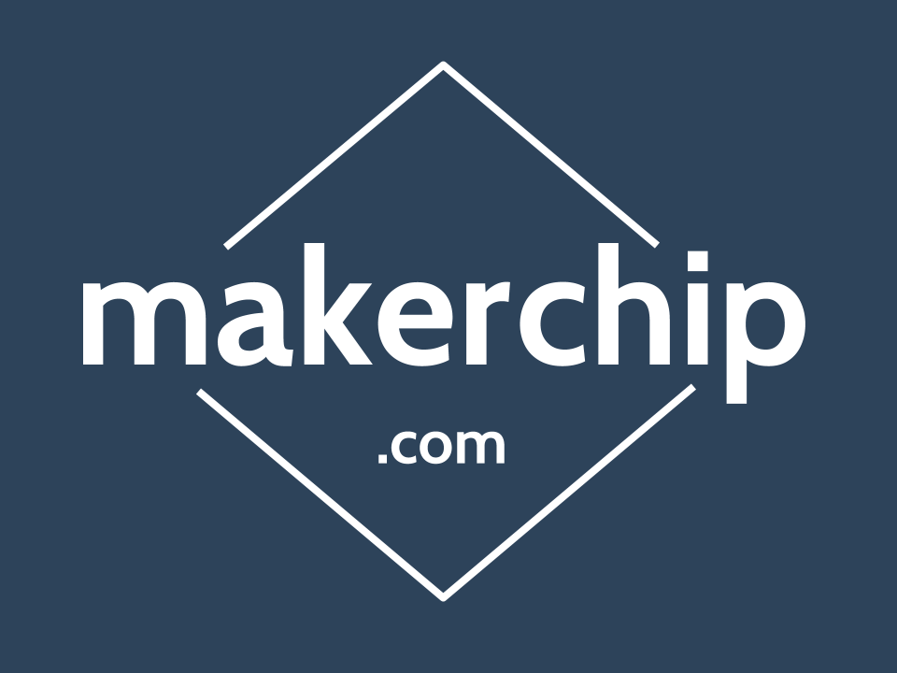
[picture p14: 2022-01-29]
images/makerchip.png

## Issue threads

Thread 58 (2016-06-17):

Libraries not found

cryarchy, 2016-06-17:
I have installed eSim on my computer (Linux Mint 17.3 Cinnamon 64-bit) and the installation was successful. However, creating a new project and opening the schematic causes a dialog with the title `Not Found` and the following content to pop-up:
```
The following libraries were not found:
- adc
- dac
- memory
- xilinx
- microcontrollers
- dsp
- microchip
- analog_switches
- motorola
- texas
- intel
- audio
- interface
- digital-audio
- philips
- display
- cypress
- siliconi
- opto
- atmel
- contrib
- power
- device
- transistors
- conn
- linear
- regul
- 74xx
- cmos4000
- eSim_Analog
- eSim_Devices
- eSim_Digital
- eSim_Hybrid
- eSim_Miscellaneous
- eSim_Power
- eSim_Sources
- eSim_Subckt
- eSim_User
- eSim_Plot
- eSim_PSpice
```

The `choose component` dialog box also indicated that **0 components loaded** and no components are available. Any help on how to resolve this will be greatly appreciated.

cryarchy, 2016-06-18:
I partially fixed the issue by downloading and adding the KiCAD libraries from https://github.com/KiCad/kicad-library. This now resulted in the error,
```
The following libraries were not found:
- eSim_Analog
- eSim_Devices
- eSim_Digital
- eSim_Hybrid
- eSim_Miscellaneous
- eSim_Power
- eSim_Sources
- eSim_Subckt
- eSim_User
- eSim_Plot
- eSim_PSpice
```
I added the libraries that are contained in the `eSim\kicadSchematicLibrary\` and now I have the error(s):

```
08:36:44 AM: Library 'eSim_PSpice' has duplicate entry name 'R_var_PSPICE'.
This may cause some unexpected behavior when loading components into a schematic.
08:36:44 AM: Library 'eSim_PSpice' has duplicate entry name 'R_var_PSPICE'.
This may cause some unexpected behavior when loading components into a schematic.
08:36:44 AM: Library 'eSim_PSpice' has duplicate entry name 'C_var_PSPICE'.
This may cause some unexpected behavior when loading components into a schematic.
08:36:44 AM: Library 'eSim_PSpice' has duplicate entry name 'C_var_PSPICE'.
This may cause some unexpected behavior when loading components into a schematic.
08:36:44 AM: Library 'eSim_PSpice' has duplicate entry name 'DB9M_PSPICE'.
This may cause some unexpected behavior when loading components into a schematic.
08:36:44 AM: Library 'eSim_PSpice' has duplicate entry name 'DB9M_PSPICE'.
This may cause some unexpected behavior when loading components into a schematic.
08:36:44 AM: Library 'eSim_PSpice' component load error Wrong DEF format in line 3184, skipped..
08:36:44 AM: Library 'eSim_PSpice' component load error Wrong DEF format in line 10037, skipped..
08:36:44 AM: Library 'eSim_PSpice' component load error Wrong DEF format in line 10052, skipped..
08:36:44 AM: Library 'eSim_PSpice' component load error Wrong DEF format in line 10067, skipped..
08:36:44 AM: Library 'eSim_PSpice' component load error Wrong DEF format in line 10082, skipped..
08:36:44 AM: Library 'eSim_PSpice' component load error Wrong DEF format in line 10097, skipped..
08:36:44 AM: Library 'eSim_PSpice' component load error Wrong DEF format in line 10112, skipped..
08:36:44 AM: Library 'eSim_PSpice' component load error Wrong DEF format in line 10127, skipped..
08:36:44 AM: Library 'eSim_PSpice' component load error Wrong DEF format in line 10142, skipped..
08:36:44 AM: Library 'eSim_PSpice' component load error Wrong DEF format in line 10157, skipped..
08:36:44 AM: Library 'eSim_PSpice' component load error Wrong DEF format in line 10172, skipped..
08:36:44 AM: Library 'eSim_PSpice' component load error Wrong DEF format in line 10187, skipped..
08:36:44 AM: Library 'eSim_PSpice' component load error Wrong DEF format in line 10205, skipped..
08:36:44 AM: Library 'eSim_PSpice' component load error Wrong DEF format in line 10220, skipped..
08:36:44 AM: Library 'eSim_PSpice' component load error Wrong DEF format in line 10235, skipped..
08:36:44 AM: Library 'eSim_PSpice' component load error Wrong DEF format in line 10248, skipped..
08:36:44 AM: Library 'eSim_PSpice' component load error Wrong DEF format in line 10261, skipped..
08:36:44 AM: Library 'eSim_PSpice' component load error Wrong DEF format in line 10273, skipped..
08:36:44 AM: Library 'eSim_PSpice' component load error Wrong DEF format in line 10285, skipped..
08:36:44 AM: Library 'eSim_PSpice' component load error Wrong DEF format in line 10297, skipped..
08:36:44 AM: Library 'eSim_PSpice' component load error Wrong DEF format in line 10308, skipped..
08:36:44 AM: Library 'eSim_PSpice' component load error Wrong DEF format in line 10319, skipped..
08:36:44 AM: Library 'eSim_PSpice' component load error Wrong DEF format in line 10337, skipped..
08:36:44 AM: Library 'eSim_PSpice' component load error Wrong DEF format in line 10355, skipped..
08:36:44 AM: Library 'eSim_PSpice' component load error Wrong DEF format in line 10371, skipped..
08:36:44 AM: Library 'eSim_PSpice' component load error Wrong DEF format in line 10386, skipped..
08:36:44 AM: Library 'eSim_PSpice' component load error Wrong DEF format in line 10401, skipped..
08:36:44 AM: Library 'eSim_PSpice' component load error Wrong DEF format in line 10413, skipped..
08:36:44 AM: Library 'eSim_PSpice' component load error Wrong DEF format in line 10428, skipped..
08:36:44 AM: Library 'eSim_PSpice' component load error Wrong DEF format in line 10441, skipped..
08:36:44 AM: Library 'eSim_PSpice' component load error Wrong DEF format in line 12053, skipped..
08:36:44 AM: Library 'eSim_PSpice' component load error Wrong DEF format in line 12133, skipped..
08:36:44 AM: Library 'eSim_PSpice' component load error Wrong DEF format in line 12155, skipped..
08:36:44 AM: Library 'eSim_PSpice' component load error Wrong DEF format in line 12180, skipped..
08:36:44 AM: Library 'eSim_PSpice' component load error Wrong DEF format in line 12261, skipped..
08:36:44 AM: Library 'eSim_PSpice' component load error Wrong DEF format in line 12273, skipped..
08:36:44 AM: Library 'eSim_PSpice' component load error Wrong DEF format in line 12286, skipped..
08:36:44 AM: Library 'eSim_PSpice' component load error Wrong DEF format in line 12299, skipped..
08:36:44 AM: Library 'eSim_PSpice' component load error Wrong DEF format in line 12431, skipped..
08:36:44 AM: Library 'eSim_PSpice' component load error Wrong DEF format in line 12444, skipped..
```
How do I fix this?

kavyamanohar, 2016-06-18:
The  libraries can be added manually. To add libraries Go to `Preferences -> component libraries -> add` . Choose the required libraries from `user/share/kicad/library`.
The libraries other than the `eSim_*` comes from kicad. If they are not found in the above location, Installing `kicad-library` package might be required.

cryarchy, 2016-06-18:
Thanks Kavya, I've fixed the issue with the libraries by installing and adding the libraries from `kicad-library`. Is there a current fix to the resulting `eSim_PSpice` errors detailed above?

fahim-oscad, 2016-06-18:
I can't find any duplicate element in eSim_PSpice. Can you check kicad.pro file and see if eSim_PSpice has been used twice ? It can be found under /usr/share/kicad/template.

cryarchy, 2016-06-18:
No it hasn't. There is only one entry for eSim_PSpice. Here is the file. I've added the `.txt` extension so that it may upload.
[kicad.pro.txt](https://github.com/FOSSEE/eSim/files/321629/kicad.pro.txt)

fahim-oscad, 2016-06-22:
In Ubuntu if we run the eSim installer it install kicad properly and create the library folder as well however in Linux Mint 17.3 (Cinnamon 64-bit) we found that library directory was not creating while installing Kicad and it has to separately install. Our installer just copy few files in library and template folder.

Here is the solution for Linux Mint after installing eSim just install kicad-library.
`sudo apt-get install kicad-library`
 This will create kicad library folder

Now just copy the .lib and .dcm files available in kicadSchematicLibrary of eSim into library folder

`sudo cp -r kicadSchematicLibrary/*.lib /usr/share/kicad/library/`
`sudo cp -r kicadSchematicLibrary/*.dcm /usr/share/kicad/library/`

We have tested this procedure in Mint and it is working. In the next version we will add the kicad-library installation as well.

cryarchy, 2016-06-22:
Thank to all you guys!

Mike6158, 2017-09-29:
I solved the problem by uninstalling KiCad and forgetting it ever existed

Closed 2016-06-23.

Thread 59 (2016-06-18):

Simulation window startup error

cryarchy, 2016-06-18:
Following the process detailed in the **eSim user manual** I am trying to simulate as detailed in chapter 6. The process is a success through to the kicadToNgSpice conversion. However, pressing on the *Simulation* button on the left-side tool bar on the eSim interface results in a window with the following info:
```
Error while opening python plotting Editor. Please look at console for more details
```
The contents of the console are:
```
eSim Started......
Project Selected : None

[INFO]: Workspace : /home/user/tizy/eSim-Workspace
[INFO]: The current project is /home/user/tizy/eSim-Workspace/Project1
[INFO]: Kicad Schematic is called for project /home/user/tizy/eSim-Workspace/Project1
[INFO]: Kicad to Ngspice Conversion is called
[INFO]: Current Project is /home/user/tizy/eSim-Workspace/Project1
[INFO]: Ngspice simulation is called : /home/user/tizy/eSim-Workspace/Project1
[INFO]: PythonPlotting is called : /home/user/tizy/eSim-Workspace/Project1
[ERROR]: Exception Message :[Errno 2] No such file or directory: '/home/user/tizy/eSim-Workspace/Project1/plot_data_i.txt'
[ERROR]: Exception Message :local variable 'alli' referenced before assignment
[ERROR]: Exception Message : [Errno 2] No such file or directory: '/home/user/tizy/eSim-Workspace/Project1/plot_data_v.txt'
[INFO]: Ngspice simulation is called : /home/user/tizy/eSim-Workspace/Project1
[INFO]: PythonPlotting is called : /home/user/tizy/eSim-Workspace/Project1
[ERROR]: Exception Message :[Errno 2] No such file or directory: '/home/user/tizy/eSim-Workspace/Project1/plot_data_i.txt'
[ERROR]: Exception Message :local variable 'alli' referenced before assignment
[ERROR]: Exception Message : [Errno 2] No such file or directory: '/home/user/tizy/eSim-Workspace/Project1/plot_data_v.txt'
[INFO]: Ngspice simulation is called : /home/user/tizy/eSim-Workspace/Project1
[INFO]: PythonPlotting is called : /home/user/tizy/eSim-Workspace/Project1
[ERROR]: Exception Message :[Errno 2] No such file or directory: '/home/user/tizy/eSim-Workspace/Project1/plot_data_i.txt'
[ERROR]: Exception Message :local variable 'alli' referenced before assignment
[ERROR]: Exception Message : [Errno 2] No such file or directory: '/home/user/tizy/eSim-Workspace/Project1/plot_data_v.txt'
```
Any insight as to how I can resolve this?

cryarchy, 2016-06-18:
I was able to resolve this problem by first running `ngspice Project1.cir.out` while in the **root folder** of my project (named *Project1*). The simulation on *terminal ngspice* flops but it generates the missing files. I then returned to the eSim interface and clicking on the *Simulation* button on the left-side tool bar on the eSim interface worked out fine. I leave this issue opened since I believe that is not the intended workflow. It may be closed if that is the intended workflow.

fahim-oscad, 2016-06-18:
What version of eSim are you using ? Did you enter 'y' to install nghdl ?

cryarchy, 2016-06-18:
Yes I did. Version: `eSim-1.1.2`

fahim-oscad, 2016-06-20:
Please raise the example related query on our forum http://forums.fossee.in/

Closing this issue.

Closed 2016-06-20.

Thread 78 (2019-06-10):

ProjectExplorer treeWidget UI

nilshah98, 2019-06-10:
The treeWidget UI for the project explorer isn't proper.
Refer attached image for more details-

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

nilshah98, 2019-06-10:
After fixing, UI looks like
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

Closed 2019-06-15.

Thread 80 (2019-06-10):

Fix NgSpice Model tab under kicadToNgspice

nilshah98, 2019-06-10:
When adding data for `NgSpice Model` under `KicadToNgspice` there are input boxes, for each letter, whereas it should be for each word.
Refer-
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

Closed 2019-06-15.

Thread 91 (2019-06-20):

Change format of .lib files from multiple lines to single lines

nilshah98, 2019-06-20:
**Issue details-**
- Currently the generated `.lib` files follow the multi line format, change it to single line format for easier use
- Device models to be generated according to the Spice's convention. Example -
- Multi Line format -
```
.MODEL PowerDiode D(
+ Vj=.75
+ Nbvl=14.976
+ Cjo=175p
+ Rs=.25
+ Isr=1.859n
+ Eg=1.11
)
```
- Single Line format -
```
.MODEL PowerDiode D( Vj=.75 Nbvl=14.976 Cjo=175p Rs=.25 Isr=1.859n Eg=1.11 )
```
Edit: Add relevant tags such as `feature` or `enhancement`
Edit: Added spice format for reference

saurabhb17, 2019-06-20:
please rephrase it as " device models to be generated according to Spice's convention"

sunilshetye, 2019-06-27:
merged into fellowship2019-python3 branch

Closed 2019-06-27.

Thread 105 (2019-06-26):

Logging feature implemented

nilshah98, 2019-06-26:
**Issue Details-**
- Logging feature to improve the ability to debug for incoming programmers
- Currently `print()` statements used everywhere
- Rather can use `logging` library from python to display more data beside the print statements

**Ideas-**
- Logging to a file, so that incase of errors, can ask the user to mail the log files, along with other necessary files as netlist to debug application.

Eyantra698Sumanto, 2021-07-08:
Okay we will look into it

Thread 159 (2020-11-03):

Installation broken on Ubuntu versions >=20.04

q-wertz, 2020-11-03:
When trying to install eSim on newer Ubuntu versions the installation of xpdf fails.
As stated [here](https://askubuntu.com/a/1245541) xpdf was dropped from Ubuntu with version 20.04.
Would it be possible for eSim to use another pdf reader?

saurabhb17, 2020-11-04:
yes of course, for Ubuntu 20.04 onward, we will use either evince or okular. Will be incorporated in next release

q-wertz, 2020-11-04:
Ok thank you very much.
I have quite some trouble installing it in Ubuntu 20.10. There are more dependencies which are broken.

saurabhb17, 2020-11-04:
You know, I have tried running eSim on Ubuntu 20 on a Virtualbox setup, surprisingly,I did not encounter the l_ibz.so.1: version `ZLIB_1.2.9_ issue.

Nevertheless, I will get back to you on this.

ThellraAK, 2020-11-15:
Manually installed xpdf from the 19.10 repos and then ran into not being able to  install gnat-5 and couldn't find a way to do the same (lubuntu 20.04)

rahulp13, 2021-01-08:
There is a new release that fixed all the above issues. It is available [here](https://esim.fossee.in/downloads). You can try it and let us know if there are any further issues.

q-wertz, 2021-01-08:
Thanks for the new release :)

The problem is, that you only support an old kicad version and this leads to the following problem(s)
```
The following additional packages will be installed:
  libboost-context1.65.1 libboost-system1.65.1 libboost-thread1.65.1 libglew2.0 libpython2-stdlib libpython2.7
  libpython2.7-minimal libpython2.7-stdlib libwxgtk3.0-0v5 python-is-python2 python-wxgtk3.0 python-wxversion
  python2 python2-minimal python2.7 python2.7-minimal
Suggested packages:
  extra-xdg-menus kicad-demo kicad-locale-ko | kicad-locale-ru | kicad-locale-pl | kicad-locale-pt | kicad-locale-ja
  | kicad-locale-id | kicad-locale-ca | kicad-locale-it | kicad-locale-el | kicad-locale-zh | kicad-locale-de
  | kicad-locale-sl | kicad-locale-cs | kicad-locale-bg | kicad-locale-sv | kicad-locale-lt | kicad-locale-fi
  | kicad-locale-fr | kicad-locale-hu | kicad-locale-nl | kicad-locale-es | kicad-locale-sk glew-utils wx3.0-doc
  python2-doc python-tk python2.7-doc
Recommended packages:
  kicad-library kicad-doc-en
The following packages will be REMOVED:
  kicad-footprints kicad-libraries kicad-symbols kicad-templates
The following NEW packages will be installed:
  libboost-context1.65.1 libboost-system1.65.1 libboost-thread1.65.1 libglew2.0 libpython2-stdlib libpython2.7
  libpython2.7-minimal libpython2.7-stdlib libwxgtk3.0-0v5 python-is-python2 python-wxgtk3.0 python-wxversion
  python2 python2-minimal python2.7 python2.7-minimal
The following packages will be DOWNGRADED:
  kicad
0 upgraded, 16 newly installed, 1 downgraded, 4 to remove and 0 not upgraded.
E: Packages were downgraded and -y was used without --allow-downgrades.

Error! Kindly resolve above error(s) and try again.

Aborting Installation...
```

Is it possible for you to use the new kicad version or are there API changes that you do not support?
I'm not a big fan of using python2 :sweat_smile:

rahulp13, 2021-01-08:
Some modules of eSim and libraries were developed for old KiCad version. So, I highly doubt its compatibility with the new KiCad version. You can manually downgrade it to proceed with the old version. Otherwise, you can proceed with the new KiCad version (comment out the KiCad installation part in the script) and let us know if it works or not. You may also send a pull request for the same, and we shall make it available in our next release.

Regarding Python2, Even I'm not a big fan of it, but it shouldn't do any harm to your usage of eSim.

Closed 2021-01-31.

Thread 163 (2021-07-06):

Missing LLVM-8 during installation script

geraldsweers, 2021-07-06:
Missing LLVM-8 during installation script

Looks i have installed LLVM12.0-52

Cant find it the config file (im still a newbe)

Eyantra698Sumanto, 2021-07-08:
The whole system of eSim is designed to work using kicad-4.0.7. Newer versions of kicad not supported. Use the kicad supported by eSim.

Eyantra698Sumanto, 2021-07-08:
We would include KiCAD 5.1 in newer release of eSim. Please let us know if you would like to contribute

Closed 2022-02-10.

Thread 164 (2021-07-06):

Install script uses old version of kicad ppa

geraldsweers, 2021-07-06:
Script uses old version of kicad ppa
I have kicad5.1.9 installed already
So i changed it to the new one for myself

Made these changes:
---------------------------------------------------

function addKicadPPA
{

    #sudo add-apt-repository ppa:kicad/kicad-5.1-releases
    kicadppa="kicad/kicad-5.1-releases"
    findppa=$(grep -h -r "^deb.*$kicadppa*" /etc/apt/sources.list* > /dev/null 2>&1 || test $? = 1)
    if [ -z "$findppa" ]; then
        echo "Adding KiCad-5 PPA to local apt-repository"
        if [[ $(lsb_release -rs) == 20.* ]]; then
            sudo apt-key adv --keyserver keyserver.ubuntu.com --recv-keys 83FBAD2D910F124E
            sudo add-apt-repository --yes "deb [trusted=yes] http://ppa.launchpad.net/kicad/kicad-5.1-releases/ubuntu>
            sudo touch /etc/apt/preferences.d/preferences
            echo "Package: kicad" | sudo tee -a /etc/apt/preferences.d/preferences > /dev/null
            echo "Pin: version 4.0.7*" | sudo tee -a /etc/apt/preferences.d/preferences > /dev/null
            echo "Pin-Priority: 501" | sudo tee -a /etc/apt/preferences.d/preferences > /dev/null
            sudo apt-key adv --keyserver keyserver.ubuntu.com --recv-keys 3B4FE6ACC0B21F32
            sudo add-apt-repository --yes "deb http://archive.ubuntu.com/ubuntu/ bionic main universe"
        else
            sudo add-apt-repository --yes ppa:kicad/kicad-5.1-releases
        fi
    else
        echo "KiCad-5 is available in synaptic"
    fi

}

------------------------------------------------------------------
and i also changed:

   echo "Installing KiCad..........................."
    sudo apt-get install -y --no-install-recommends kicad=5.1.9*
    if [[ $(lsb_release -rs) == 20.* ]]; then
        sudo add-apt-repository -ry "deb http://archive.ubuntu.com/ubuntu/ bionic main universe"
    fi

---------------------------------------------------------------

Dont know how to send changes otherway. Im a newbe and afraid to dammage the installer script for others.

Maybe someone can update the script
im looking also for llvm-12 version support. script doesnt find llvm-8 but still looking how to solve that one. See other issue

Greetings
Gerald

Eyantra698Sumanto, 2021-07-08:
The whole system of eSim is designed to work using  kicad-4.0.7. Newer versions of kicad not supported.

Eyantra698Sumanto, 2021-07-08:
We would include KiCAD 5.1 in newer release of eSim. Please let us know if you would like to contribute.

Eyantra698Sumanto, 2022-11-01:
@geraldsweers Hi. Any update? Would you like to contribute?

satyap99, 2023-02-22:
@Eyantra698Sumanto I tried installing this pkg on Ubuntu 22.04 and encountered multiple errors
1) Kicad 4.0.7 incompatibility with the install script so I changed it to the latest Kicad-6 and it worked then I faced the 2nd problem 2) Incompatibility with llvm-9 which is not available by default on the latest Ubuntu version. So I tried to change the nghdl.sh script to change the value of variable "llvm_version" to "14" instead of "9". Even after changing it defaults to version 9 of llvm. Can you tell me if there is any other function that's not letting me overwrite the "llvm_version" variable.

Eyantra698Sumanto, 2023-02-22:
@satyap99 Thanks for writing to us.

Please remove llvm-9 first by running the following command: `sudo apt-get purge -y llvm-9 llvm-9-dev` and then run the eSim/NGHDL install script. Please let us know if this doesn't work.

Also, it is great that you were able to install Kicad-6. We are in the progress of shifting to Kicad-6 in the next version of eSim. Thank You.

satyap99, 2023-02-22:
@Eyantra698Sumanto Actually while running the script it's not able to install llvm-9 as the package in the current version of Ubuntu. Even after changing the llvm_version to 14 in NGHDL script I don't know how it gets overwritten by llvm-9 when I'm running the main install script.

Eyantra698Sumanto, 2023-02-22:
@satyap99 Please see line 61 of the [install-eSim.sh](https://github.com/FOSSEE/eSim/blob/installers/Ubuntu/install-eSim.sh). There is a compressed file named **nghdl.zip** where the install-nghdl.sh exists. When you run install-eSim.sh the nghdl.zip gets extracted and overwrites the install-nghdl.sh which you have changed.

So, please comment on the 61st line of the [install-eSim.sh](https://github.com/FOSSEE/eSim/blob/installers/Ubuntu/install-eSim.sh), make the required changes to the **install-nghdl.sh**, and run the installer again. Please let us know if this doesn't work.

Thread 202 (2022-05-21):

Default curve fitting problem in Python Plot

Eyantra698Sumanto, 2022-05-21:
The plot of python plot does not replicate that of ngspice for parameter sweeping instead looks something like a raster scan.
Ngspice Plot:
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
Python Plot:
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

PFA of a zipped project file too replicate/investigate the issue:
[LTspice_IGBT.zip](https://github.com/FOSSEE/eSim/files/8748251/LTspice_IGBT.zip)

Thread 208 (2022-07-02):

Not updating Previous Values.xml of Project

PatelVatsalB21, 2022-07-02:
### Description
While simulating the circuit, if the user changes values in KicadtoNgspice or changes components in schematic and then changes values in KicadtoNgspice, it doesn't respond to the **Convert** button. Also, it shows an error in the ESim terminal as attached below.

If this error is encountered once, then it will repeat even on changing the project until the previous_values.xml file is deleted.

### Screenshots
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

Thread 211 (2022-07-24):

Automate the packaging of eSim

Eyantra698Sumanto, 2022-07-24:
### Description

Currently the packaging in eSim is done manually.

However, it is difficult to package everything and follow the steps as new features get added on.

It also takes huge amount of time and the developer also needs to go through a proper checklist.

We need to automate the packaging of eSim to solve the above problems.

### Steps to Reproduce

Automate the packaging of eSim.

### Expected Behavior

A script/code should package the eSim automatically and the developer must have to do minor changes to the script whenever there are change in modules.

### Version and OS

 - eSim-2.2 onwards
 - OS:  Windows (whichever supported by eSim)

saicharan0112, 2022-10-04:
@Eyantra698Sumanto What do you mean by packaging (I mean which branches are packed together)? I have been developing CI for a few opensource tools. Maybe I can help you in packaging and releasing the eSim automatically.

Eyantra698Sumanto, 2022-10-04:
@saicharan0112 Please have a look at the following repository: https://github.com/FOSSEE/eSim/tree/installers/Windows

We are planning to automate the packaging of eSim Windows. Currently, the installers for the same are created manually and then passed to NSIS. But we want to automate the process.

Please give us your valuable comments!!!

Thank You.

saicharan0112, 2022-10-04:
@Eyantra698Sumanto This looks pretty much straight forward to me. It can be done using GHA without any hustle. Do you want me to try for Ubuntu?

Eyantra698Sumanto, 2022-10-05:
@saicharan0112 Yes it would be great if you could try and let us know!!!

Eyantra698Sumanto, 2022-10-23:
@saicharan0112 If you have any update, please let us know.

saicharan0112, 2022-10-23:
@Eyantra698Sumanto Definitely. I will give an update this week. I was busy with my office work all these days.

saicharan0112, 2022-10-30:
@Eyantra698Sumanto Here is the release that is automatically done by GHA - https://github.com/saicharan0112/eSim/releases/tag/test_tag1

Can you check whether it has all the required files?

If so, I can create a PR so that you people can use it for eSim Ubuntu release

Eyantra698Sumanto, 2022-10-30:
@saicharan0112, Thanks a lot. I quickly went through it. Can you please provide us with a doc or readme mentioning the steps on how you automate it using GHA. Also, please correct the file name "nghld.zip" to "nghdl.zip". We will look into other files carefully and give some more comments in some time.

@rahulp13 feel free to comment.

saicharan0112, 2022-10-30:
@Eyantra698Sumanto Checkout these jobs - https://github.com/saicharan0112/eSim/actions/runs/3356398346/jobs/5561435527

Their names should give you the idea of steps.. This GHA should take care of all the steps you mentioned in this readme file https://github.com/FOSSEE/eSim/tree/installers/Ubuntu

saicharan0112, 2022-10-30:
It also create a release whenever you create a tag starting with "v"

Eyantra698Sumanto, 2022-10-31:
@saicharan0112 Thanks Sai. It looks quite good. Yes, please create a pull request. Also, for Windows, will the GHA be feasible? We are using the NSI script for installation and all stuff.

saicharan0112, 2022-10-31:
@Eyantra698Sumanto I would like to point out two things in this improvement, which I hope you already observed.
* It doesn't check for eSim executable. It directly copies the source code (src/ folder) from nghdl and eSim.
* I couldn't find any eSim_manual.pdf file in the library/figures something location. However, I observed that we are deleting all the content except this pdf (if present). Is that what you would expect?

Eyantra698Sumanto, 2022-10-31:
@saicharan0112

- Yay correct. eSim doesn't have an executable binary as of now. This approach should be correct. However, I need to install them to test them.
- Earlier eSim had an HTML-based manual. However, we switched on to LaTeX now. So, the eSim_manual.pdf needs to be there. Here is the link to the eSim manual: https://static.fossee.in/esim/manuals/eSim_Manual_2.3.pdf

rahulp13, 2022-10-31:
@saicharan0112  your gha for Ubuntu looks promising. Some tweaks may be required, but you can proceed with the PR. Regarding the manual, we can automate it by fetching it from the above URL pattern.

saicharan0112, 2022-10-31:
We could use wget to download the manual or build the manual in gha too...
Where the tex files are stored in this repo?

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

rahulp13, 2022-10-31:
Please check the [manual branch](https://github.com/FOSSEE/eSim/tree/manual). Note that `main.tex` is the starting file.

saicharan0112, 2022-10-31:
Can you provide the list of commands you all usually follow to build the pdf file using these tex files?

Eyantra698Sumanto, 2022-10-31:
@saicharan0112 Generally we do everything in Overleaf. However please have a look here: https://github.com/aslushnikov/latex-online

saicharan0112, 2022-10-31:
@Eyantra698Sumanto @rahulp13 I am not sure about automating the manual build using GHA cuz it looks like it requires hard-coding the name of latex files and figures, which I usually don't encourage. I see additional files in the manual branch. Can we reorganise the files and images, maybe placing them all in a single folder, so that we can run that folder directly using https://github.com/aslushnikov/latex-online .

saicharan0112, 2022-10-31:
If the manual is first updated in the location https://static.fossee.in/esim/manuals/*, I can just pull "https://static.fossee.in/esim/manuals/eSim_Manual_$tag.pdf" based on the tag you use for release (which is in sync with the release here on github). Hows that?

Eyantra698Sumanto, 2022-10-31:
@saicharan0112: https://static.fossee.in/esim/manuals/eSim_Manual_$tag.pdf should be a good solution.

@rahulp13 what's your opinion?

saicharan0112, 2022-11-02:
Any updates on this?

saicharan0112, 2022-11-02:
> @saicharan0112 your gha for Ubuntu looks promising. Some tweaks may be required, but you can proceed with the PR. Regarding the manual, we can automate it by fetching it from the above URL pattern.

@rahulp13 What do mean by tweaks? Can't those be in this PR?

Eyantra698Sumanto, 2022-11-02:
@saicharan0112 please proceed with https://static.fossee.in/esim/manuals/eSim_Manual_$tag.pdf

saicharan0112, 2022-11-06:
@Eyantra698Sumanto Sure. I was actually waiting for @rahulp13 's comments. I missed his thumbs up reactions. Apparently GitHub won't notify you when emojis are used in conversations.

I will create a PR once I get some time.

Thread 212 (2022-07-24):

Only one field in KiNg Conversion for same multiple Subcircuit and Device Model components

Eyantra698Sumanto, 2022-07-24:
### Description

Currently, multiple fields get created for the subcircuit/deveice model even for the same block.

While only one field is required, other fields may be redundant.

This also takes a lot of time for the user to fill all the fields.

### Steps to Reproduce

- Build a schematic using a subcircuit component say "CMOS_NAND". The schematic should contain two  "CMOS_NAND"s.
- Create netlist in KiCad
- In eSim main window, click onthe "KiCad to Ngspice Convert"
- Click on 'Subcircuits" Tab
- One will see two fields of "CMOS_NAND".

### Expected Behavior

- After clicking on the 'Subcircuits" Tab
- One should see one field of "CMOS_NAND".

### Screenshots
Multiple fields for inv can be seen here:

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

### Version and OS
 - eSim version-2.2
 - OS: Windows 10, Windows-8, Ubuntu 18.04, Ubuntu 20.04

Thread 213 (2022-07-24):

Ngspice is CASE insensitive

Eyantra698Sumanto, 2022-07-24:
### Description

Ngspice is CASE insensitive.

However, if we need path of a directory to be passed in netlist, say "/home/sumanto/Desktop" gets converted to"/home/sumanto/desktop".

A temporary fix has been decided to add a '$' before the CAPITAL letters to identify them.

### Expected Behavior

Ngspice should be CASE sensitive for paths, string values, etc.

### Version and OS
 - eSim 2.2
 - OS: Windows 10, 64 bit, Ubuntu 20.04, 64 bit

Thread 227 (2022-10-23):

Auto-detecting the previously installed eSim version

Eyantra698Sumanto, 2022-10-23:
### Description
The current eSim installer does not detect the previously installed eSim version.

This causes various path problems and problems with rewriting the files.

### Expected behavior
The installer should be able to detect the previously installed eSim.

Ask the user whether to remove it or not.

If the user permits, the previously installed eSim must be removed completely and then the installation of the new version of eSim must begin.

### Version and OS
 - eSim-2.3
 - OS: Windows 10

saicharan0112, 2022-10-31:
This part can be useful I guess - https://github.com/FOSSEE/eSim/blob/installers/Ubuntu/install-eSim.sh#L374. If these locations have any eSim traces, a message can be printed for the user confirmation and perform uninstallation part of the same script and begin the new version installation.
@Eyantra698Sumanto What do you say?

Eyantra698Sumanto, 2022-10-31:
@saicharan0112 Thanks for letting me know. However, this issue is basically for the Windows OS...

092vk, 2024-11-14:
I have solved this problem by making changes to the esim-setup-script.nsi script in windows folder in Installers branch . But how can i test my NSIS script , in readme.md of windows two options are listed - [esim-executable](https://github.com/092vk/eSim/tree/installers/Windows#esim-executable) and [How to package eSim](https://github.com/092vk/eSim/tree/installers/Windows#how-to-package-esim) . Which one should i follow to test my esim-setup-script.nsi script. Do i have to repackage to test it .

Eyantra698Sumanto, 2024-11-15:
@092vk At first, the eSim executable must be created using the [esim-executable](https://github.com/092vk/eSim/tree/installers/Windows#esim-executable) script.

Then, the created executable needs to be added and packaged as given in the [How to package eSim](https://github.com/092vk/eSim/tree/installers/Windows#how-to-package-esim). The NSIS script needs to be run to create the eSim Installer using the packages. Now, the eSim can be installed and tested using the newly created installer.

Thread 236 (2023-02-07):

eSim crashing upon converting subcircuit to nspice.

hrittikag, 2023-02-07:
### Description

While creating a subcircuit, when we try to convert the kicad model to ngpsice, eSim crashes and becomes unresponsive.

### Steps to Reproduce

1. Start eSim
2. Go to the subcircuit tab in the left menu and create a subcircuit.
3. A new schematic sheet opens. Edit the schematic with a circuit and save it.
4. Open esim and again go to the subcircuit tab. Click on the 'convert kicad to ngpsice' option. Upon doing this, you might notice esim becomes unresponsive and crashes after a while.

### Expected Behavior

Expected eSim to successfully convert kicad model to ngspice and create the subcircuit.

### Screenshots

<!--- If applicable, add screenshots to help explain your problem. -->
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

### Version and OS

<!--- Please complete the following information. -->

 - eSim version: eSim 2.2
 - OS: Windows 10, 64 bit

<!--- Add any other context about the problem here. -->

rahulp13, 2023-02-08:
@hrittikag, please specify the steps to reproduce the error, right from launching eSim till one gets the error.

Eyantra698Sumanto, 2023-02-15:
Solved in the following pull request #231.

Eyantra698Sumanto, 2023-09-02:
eSim crash when attempting to open or edit a Subcircuit schematic without selecting a project fixed in #256.

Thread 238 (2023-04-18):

To add various UI plot features in Python Plotting of eSim

Eyantra698Sumanto, 2023-04-18:
### Description

To add various UI plot features in Python Plotting of eSim( like:

1. To find dy/dx or the slope of the plots
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

2. To stack the plots one above the other:
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

3. Zoom to open in a new window:
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

Any many more? Please feel free to add more.

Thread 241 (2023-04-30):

Crash eSim on opening/editing a schematic without any project selection.

PSR0001, 2023-04-30:
### Description
eSim crash on opening/editing a schematic without any project selection.

### Steps to reproduce
1. Open eSim
2. go to the subcircuit tab
3. New Subcircuit Schematic / Edit Subcircuit Schematic

### Expected behavior
After clicking ```New Subcircuit Schematic / Edit Subcircuit Schematic ```  eSim should open the subcircuit schematic without crashing.

### Version and OS
 - eSim version 2.3
 - OS: Windows 11, 64 bit

Closed 2023-09-02.

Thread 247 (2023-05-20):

Bug at the scrolling pad of console area

ROSHAN0120, 2023-05-20:
### Description
The scrolling pad at the console area is not proper. The arrows are not  clearly visible .

### Steps to reproduce
Just open esim and carefully notice the console area , specially the scrolling tab

### Expected behavior
The arrows must be visible and the scroll rod must not overlap its boundary .

### Additional files
I have recorded the bug and its shared through drive  : https://drive.google.com/file/d/1dbbzWllae77zyV7O4DHaYHLreIt2oYiC/view?usp=share_link

### Version and OS
 - eSim version - 2.2
 - OS:  Windows 10, 64 bit

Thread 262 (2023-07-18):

eSim crashes while using Remove lint_off option

Eyantra698Sumanto, 2023-07-18:
### Description

While removing a lint_off option "x not in the list" occurs and eSim crashes

### Steps to Reproduce

1. Run Makerchip-Ngveri
2. Switch to the NgVeri Tab
3. Replace the lint_off.txt file already present at $(eSim_HOME\library\tlv with the one provided in the attachment([lint_off.txt](https://github.com/FOSSEE/eSim/files/12082751/lint_off.txt)).
4. Click on the "Remove lint_off" in the NgVeri Tab.
5. Try removing the "COMCONST" by clicking on it.
6. eSim will crash will the error message "x not in the list" in the background terminal."

### Expected Behavior

eSim should be able to remove the lint_off option otherwise pop-up dialog must be provided if eSim is not able to remove a lint_off option stating the user to do it manually by opening the lint_off.txt file.

### Screenshots

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

### Version and OS

<!--- Please complete the following information. -->

 - eSim version
 - OS: [e.g. Windows 10, 64 bit]

### Additional Context
Please find the attached lint_off.txt.
[lint_off.txt](https://github.com/FOSSEE/eSim/files/12082751/lint_off.txt)

Closed 2025-06-08.

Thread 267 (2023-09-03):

Missing or Unavailable "Switch" component

vishnunithyasoundhar, 2023-09-03:
### Description
Basic switch component is missing or unavailable in the eSim library, in the Schematics designer.

I tried searching the forums, but it wasn't mentioned anywhere oddly.

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
The above is an image of the mentioned switch component.

### Screenshots
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

### Version and OS
 - eSim version 2.3
 - OS: Windows 10

### Additional Details
I am submitting this under the guidance of Dr. Maheswari R, Vellore Institute of Technology, Chennai
Name: VishnuNithyaSoundhar S
ID: 23MCS1021

Eyantra698Sumanto, 2023-09-03:
@vishnunithyasoundhar eSim does not support Real-Time Simulation hence a switch is as good as a closed circuit or an open circuit.

In order to implement the functionality of a switch, you may use the aswitch under eSim_Analog libraries. You may input the Pulse or a PWL source at the input terminal of the aswitch to control the switch where the high means switch is closed, and the low means switch is open. Try implementing the same in this way.

If you have some other thing in mind to implement the switch, please feel free to share here.

Please feel free to ask any more queries.

vishnunithyasoundhar, 2023-09-04:
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

Thank you for your guidance. I will use aswitch in place of switch for the schematic 🙏

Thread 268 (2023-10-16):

eSim closes when simulation is initiated

Souradeep-Zidane, 2023-10-16:
### Description

Whenever I try to simulate a circuit and press the simulation button, eSim closes itself and does not run the simulation at all.

### Expected Behavior

The software is expected to run the simulation and show me if  there are any issues with my circuit.
I am not even able to run the programs given in the examples folder that were already pre-loaded during installation

<!--- If applicable, add screenshots to help explain your problem. -->

### Version and OS

 - eSim version 2.4
 - OS: Windows 11 (Version_22H2), 64 bit
 - Processor - Intel i5 12450H
 - RAM - 16GB

<!--- Add any other context about the problem here. -->

Eyantra698Sumanto, 2023-12-09:
@Souradeep-Zidane Sorry for late reply. Please send the screenshot of the background(black) terminal just before eSim closes. Thanks.

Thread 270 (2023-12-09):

Ports on the same line are not getting parsed while running NgVeri

Eyantra698Sumanto, 2023-12-09:
### Description

Ports on the same line are not getting parsed while running NgVeri

### Steps to Reproduce

- Save the following file as add.v using a text editor.
```
module add(input [3:0] A, input [3:0] B, output [3:0] S, output C);
wire [3:0] carry;
assign carry[0] = 1'b0; // No carry in for least significant bit
assign carry[1] = A[0] & B[0]; // Carry generated by bit 0
assign carry[2] = (A[1] & B[1]) | (carry[1] & (A[1] ^ B[1])); // Carry generated by bit 1
assign carry[3] = (A[2] & B[2]) | (carry[2] & (A[2] ^ B[2])); // Carry generated by bit 2
// Generate the sum bits for each bit position
assign S[0] = A[0] ^ B[0]; // Sum for bit 0
assign S[1] = A[1] ^ B[1] ^ carry[1]; // Sum for bit 1
assign S[2] = A[2] ^ B[2] ^ carry[2]; // Sum for bit 2
assign S[3] = A[3] ^ B[3] ^ carry[3]; // Sum for bit 3
// Generate the overall carry output
assign C = carry[3];
endmodule
```
- Open eSim
- Click on the Makerchip-NgVeri icon on the Left-Hand Side toolbar
- Add the file using the **Add Top Level Verilog File** button
- Run **Convert Verilog to Ngspice** from the NgVeri tab.
- The error occurs.
### Expected Behavior
- The following code works fine:
```
module add(
input [3:0] A,
input [3:0] B,
input Cin,
output [3:0] S,
output C);
// S is the sum output and C is the carry output
// A and B are the inputs
// Generate the carry bits for each bit position
wire [3:0] carry;
assign carry[0] = Cin; // No carry in for least significant bit
assign carry[1] = A[0] & B[0]; // Carry generated by bit 0
assign carry[2] = (A[1] & B[1]) | (carry[1] & (A[1] ^ B[1])); // Carry generated by bit 1
assign carry[3] = (A[2] & B[2]) | (carry[2] & (A[2] ^ B[2])); // Carry generated by bit 2
// Generate the sum bits for each bit position
assign S[0] = A[0] ^ B[0]; // Sum for bit 0
assign S[1] = A[1] ^ B[1] ^ carry[1]; // Sum for bit 1
assign S[2] = A[2] ^ B[2] ^ carry[2]; // Sum for bit 2
assign S[3] = A[3] ^ B[3] ^ carry[3]; // Sum for bit 3
// Generate the overall carry output
assign C = carry[3];
endmodule
```
- The code should work fine even with one line declaration of the ports

### Screenshots

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
### Version and OS

<!--- Please complete the following information. -->

 - eSim version: 2.4
 - OS:  Windows 11, 64 bit

### Additional Context

<!--- Add any other context about the problem here. -->

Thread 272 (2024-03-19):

eSim-2.4 unable to convert digital circuit from kicad to NgSpice

ashwini0921, 2024-03-19:
### Description

<!--- A clear and concise description of what the bug is. -->
I tried a simple digital AND gate circuit, I am unable to convert KiCad to NgSpice.
### Steps to Reproduce

<!--- This could be a list of actions and possibly the eSim project files -->
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
[and_test-20240319T082955Z-001.zip](https://github.com/FOSSEE/eSim/files/14647675/and_test-20240319T082955Z-001.zip)

1) Unzip the and_test file
2) In eSim open project, locate the and_test folder
3) click convert KiCad to NgSpice option
### Expected Behavior

<!--- A clear and concise description of what you expected to happen. -->
A dialog box should appear showing source details, type of analysis
### Screenshots

<!--- If applicable, add screenshots to help explain your problem. -->

### Version and OS
ubuntu 20.04.6 LTS
<!--- Please complete the following information. -->

 - eSim version - 2.4
 - OS: [e.g. Windows 10, 64 bit]
Ubuntu 20.04.6
### Additional Context

<!--- Add any other context about the problem here. -->

rudrakshpeps, 2024-05-31:
Same issue i am also facing on windows 11

Eyantra698Sumanto, 2024-09-07:
@rudrakshpeps For now can you try out eSim-2.3 on Windows 11. We are fixing the above issue in the next release.

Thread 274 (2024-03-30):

eSim 2.4 unable to edit subcircuit

ashwini0921, 2024-03-30:
### Description

<!--- A clear and concise description of what the bug is. -->
Firstly, I create the sub-circuit, it is created successfully, but when I tried to edit the sub-circuit, it showing a dialog box telling no schematic is present and whether I want to create one.

### Steps to Reproduce

<!--- This could be a list of actions and possibly the eSim project files -->

### Expected Behavior

<!--- A clear and concise description of what you expected to happen. -->
It should open the schematic which I initially created

### Screenshots

<!--- If applicable, add screenshots to help explain your problem. -->

### Version and OS

<!--- Please complete the following information. -->

 - eSim version 2.4
 - OS: [e.g. Windows 10, 64 bit] Ubuntu 20.04.6 LTS

### Additional Context

<!--- Add any other context about the problem here. -->

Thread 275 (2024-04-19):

esim 2.4 File is not Shown in esimSubckt Library

Krishna-saran, 2024-04-19:
esim version 2.4 for windows 64 bit have an issue regarding esim subckt libraray.
when Create Subcircuit file click on edit/delete/insert button than the new window is open when we click on filter and select on esim_subckt libraray our file is not found which we created.
But, when we close esim and check on FOSSEE folder->esim->library->subckt libraray->File(present) which is not shown in sub_ckt while running in esim.

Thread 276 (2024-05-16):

Unable to attach Power Flag (PWR_FLAG) to Ground node

AdityaMino, 2024-05-16:
### Description

Upon connecting a Voltage source to the ground using the component "eSimGND" and running the ERC, I faced an error that stated the following "Input power pin not driven by any output power pins" or "Pin-connected to some others pins but no pin to drive it ".

### Steps to Reproduce

<!--- This could be a list of actions and possibly the eSim project files -->

### Expected Behavior

Connecting a ground pin to the negative of the voltage source is a routine task done to provide a positive voltage source and a path to the earth to complete a circuit. In other versions of Ki-Cad this is fixed by adding PWR_FLAG, but in eSim2.4, the power flag is missing

### Screenshots

<!--- If applicable, add screenshots to help explain your problem. -->

### Version and OS

 - eSim 2.4
 - OS: Windows 10, 64 bit

### Additional Context

<!--- Add any other context about the problem here. -->

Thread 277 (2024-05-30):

Issue while installing eSim 2.3 on Ubuntu

rudrakshpeps, 2024-05-30:
### Description
### Steps to Reproduce

<!--- A clear and concise description of what the bug is. -->
In eSim 2.3 folder
Opened the terminal
executed the following command
$ chmod +x install-eSim.sh
$ ./install-eSim.sh --install

### Expected Behavior
Installation complete without any issue

### Screenshots
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

### Version and OS

 - eSim version : eSim-2.3
 - OS: [e.g. Windows 10, 64 bit] Ubuntu Lts 24.04

### Additional Context

Eyantra698Sumanto, 2024-06-14:
@rudrakshpeps eSim-2.4 is not supported on Ubuntu 24.04. It is supported on Ubuntu20.04 and Ubuntu 18.04. Would you like to help us in this regard?

avinashlalotra, 2024-09-06:
@Eyantra698Sumanto I attempted to resolve the installation issue on Ubuntu 24.04. Since python3-distutils is deprecated in Python 3.12 (the version used by Ubuntu 24.04), we can use setuptools as a replacement.

After installing other required packages manually - there’s another issue: esim relies on an older version of KiCad that is no longer available from any host. We will need to manually build this version of KiCad and, most likely, host the package ourselves.

I tried to build the kicad but got few errors.

Eyantra698Sumanto, 2024-09-07:
@avinashlalotra Thanks for your comment. It would be great if you can contribute. Can you create a PR on whatever fixes you have done?

Did you try installing KiCad-6 using the following command:

```
sudo add-apt-repository ppa:kicad/kicad-6.0-releases
sudo apt update -y
sudo apt -y install kicad
```

Please feel free to reply here.

avinashlalotra, 2024-09-07:
@Eyantra698Sumanto You are Welcome .
The method you provided for installing KiCad 6.0 isn't functioning on Ubuntu 24.04, although it works on 20.04 and 22.04. Currently, I’ve encountered three issues with Ubuntu 24.04:
```
1. KiCad Installation: The installation process for KiCad is problematic on this version.
2. System-Wide Package Installation: It's not possible to install system-wide packages using pip in Ubuntu 24.04.
 Packages should be installed via apt or another appropriate method. Alternatively, this can be managed within a Python virtual environment.
3. LLVM-9 Installation: Installation of LLVM-9 fails during the nghdl sh script.
```

Eyantra698Sumanto, 2024-09-07:
@avinashlalotra Yes, the problem exists and the dependencies get deprecated for every new version of Ubuntu.

We were trying to get everything on Flatpak. There was some progress done at #244. It will be great if you could help us in completing it.

avinashlalotra, 2024-09-08:
@Eyantra698Sumanto I'll do my best to help with this issue.
I'm new to Flatpak, but I'll familiarize myself with it and aim to make a meaningful contribution.

avinashlalotra, 2024-11-16:
@Eyantra698Sumanto
I have successfully managed to get esim running on Ubuntu 23.04. During the process, I encountered several issues and resolved them as follows:

## Issues Encountered & Resolutions:
# LLVM 9 Compatibility:
Ubuntu 23.04 does not have LLVM version 9 available in its repositories. To work around this, I built LLVM 9 locally. While this works for local setups, it's not ideal for production environments.

# Verilator and GHDL Issues:
There were minor compatibility issues with both Verilator and GHDL. These have been addressed and resolved, ensuring that esim now runs successfully on my system.

## Next Steps:
I plan to submit a clean-up PR by the end of next week, which will include a script for automating the build process.
Note: Building LLVM 9 manually is required for the current solution, but this is time-consuming and not suitable for production pipelines.

## Exploring LLVM 18:
In the meantime, I am investigating the possibility of compiling GHDL with LLVM 18 as a more modern and potentially compatible solution. However, I cannot confirm yet whether this will work, as further testing is required.
## Conclusion:
I will update the PR with a script to automate setup once the clean-up is complete.
If anyone is interested in testing with LLVM 18 or has suggestions for optimizing this process, feel free to reach out.

Eyantra698Sumanto, 2024-11-16:
Thanks a lot @avinashlalotra for the updates!!! It's a great progress.

@jayanth-4547 is also looking into the issue. Maybe you both can collaborate.

If required, it is better to explore higher versions of GHDL and LLVM. Building from source is not a feasible solution as it would take a lot of time and consume a lot of resource, build issues.

If anything, please feel free to reply in this thread.

Thanks!!!

Jayanth-4547, 2024-11-18:
@avinashlalotra
Hi, this is Jayanth.

I’m currently working on the same issue and have managed to successfully run eSim as well.
For my setup, I have used **llvm_version="15"** and **ghdl="ghdl-gha-ubuntu-22.04-llvm"**, and everything seems to be working fine.

Currently, I’m addressing an issue with the centering of the dialog boxes and the eSim application itself, as they are positioned at the top-right corner.
Here’s an example:
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

Have you experienced the same issue? If so, I’d appreciate any insights you might have on resolving it.

Additionally, I’m curious to know how you’ve handled the **Hdlparse**, **Makerchip**, and **SandPiper SaaS** modules.

Looking forward to your response!

avinashlalotra, 2024-11-21:
@Jayanth-4547
Hi Jayanth,

Regarding the issue with centering the dialog boxes, I am not familiar with the solution. I suggest reviewing the codebase, as I believe you will be able to identify the approach.

You can install hdlparse and other required packages within a virtual environment. It is also recommended to run eSim in that environment for consistency.

I am currently working on a  installation script of eSim . Focusing our efforts on Ubuntu 23 should allow eSim to be released for Ubuntu 23 by the end of this year.

avinashlalotra, 2024-12-01:
@Eyantra698Sumanto
Hi Sumanto,

Could you please test the following repository for installing eSim 2.4 on Ubuntu 23?
https://github.com/avinashlalotra/esim_ubuntu_installation

This should work without any issue with llvm version.
And I used GHDL 4.1.0 in it along with minor changes in verilator source . It will succesfully build with the modified script.

I've already tested it on Ubuntu 22 and 23. If you encounter any issues, kindly share your feedback so I can address them and push the necessary fixes.

Thank you!

Eyantra698Sumanto, 2024-12-02:
Thanks a lot Avinash! We will check this in sometime and get back to you. Thanks again.

Eyantra698Sumanto, 2025-01-11:
Thanks @AbhijitBaral . Will update this.

Eyantra698Sumanto, 2025-01-11:
@AbhijitBaral Also you may contribute to the repository by creating a PR. Please feel free to create a PR.

AbhijitBaral, 2025-01-11:
I checked. The necessary changes are already present..

Aishw31, 2025-03-14:
Hi @Eyantra698Sumanto

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

Hi @Eyantra698Sumanto,

@avinashlalotra and I collaborated on this repository to fix the issues we faced while installing eSim on Ubuntu 23. The changes have been successfully merged into the installer_branch.

It all started when I applied for the FOSSEE Winter Internship 2024. Unfortunately, I wasn’t selected, but that didn’t demotivate me. Instead, @avinashlalotra and I successfully fixed the issues.

This year, I am applying for the FOSSEE Summer Fellowship, and I hope to make it this time. While going through the screening tasks, I noticed that the second task is the same issue we had already fixed. However, there might be other issues we didn’t encounter. As far as I know, it was working on Ubuntu 23/22.

Should I submit this task again, or can my previous contribution be considered?

avinashlalotra, 2025-03-14:
Hi @Aishw31,

It was fun collaborating with you! I hope you make it into the summer fellowship this time. Wishing you all the best!

FOSSEE is a great organization to work with. I was a Semester-Long Intern in 2024 and am still working on publishing the Signal Processing Toolbox. The mentors are very supportive.

Eyantra698Sumanto, 2025-04-08:
Hi @Aishw31, sorry for the delayed reply. Thanks for commenting here. We will consider your previous submission as the Fellowship task. Please send an email to contact-esim@fossee.in. Best of luck!

Aishw31, 2025-04-09:
Hi @Eyantra698Sumanto, Thank you for your response.
I have mailed it to the specified address. I'm looking forward to contributing more to eSim.

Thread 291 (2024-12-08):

Python plot for DC anylasis doesn't give the plots in 2.4 version

092vk, 2024-12-08:
### Description
In eSim version 2.4, which utilizes Python plots for simulation results, users currently face an issue where DC analysis plots are not being generated; we only get a successful simulation message. In comparison, earlier versions of eSim, which used ngspice for simulations, were able to provide DC analysis plots.

### Steps to reproduce
Choose one of the examples (BJT amplifier ) , click on simulation button.

### Expected behavior
We should get plots for DC anylasis

### Screenshots
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

### Version and OS
 - eSim 2.4
 - OS: Win 11

### Additional context
It works fine in older versions.

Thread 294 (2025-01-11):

kiCad to ngspice window doesnot open

AbhijitBaral, 2025-01-11:
### Description
After exporting netlist from eeschema, the kiCad to ngspice converter window doesnot open when the appropriate option is clicked

### terminal flow trace
```
Function: Validating New Project Information
Function : Open Kicad Schematic
Function : Validating for Kicad components
Worker Thread Calling Command : eeschema /home/abhijit/eSim-Workspace/test/test.kicad_sch
Function: Open Kicad to Ngspice Converter
Function : Validating for Kicad components
==================================
Kicad to Ngspice netlist converter
==================================
.title KiCad schematic
vin1 input GND sine
ip_voltage1 input plot_v1
R2 GND output 10k
R1 input output 10k
op_voltage1 output plot_v1
.end
Traceback (most recent call last):
  File "/home/abhijit/eSim-2.4/src/projManagement/Kicad.py", line 213, in openKicadToNgspice
    self.obj_dockarea.kicadToNgspiceEditor(var)
  File "/home/abhijit/eSim-2.4/src/frontEnd/DockArea.py", line 228, in kicadToNgspiceEditor
    self.kicadToNgspiceLayout.addWidget(MainWindow(clarg1, clarg2))
  File "/home/abhijit/eSim-2.4/src/kicadtoNgspice/KicadtoNgspice.py", line 95, in __init__
    schematicInfo, sourcelist = obj_proc.insertSpecialSourceParam(
  File "/home/abhijit/eSim-2.4/src/kicadtoNgspice/Processing.py", line 148, in insertSpecialSourceParam
    if words[3] == "pulse":
IndexError: list index out of range
```
### Version and OS
 - eSim version : 2.4
 - OS: Ubuntu 20.04.6
-  KiCad: 6.0.11-2627ca5db0~126~ubuntu20.04.1, release build

092vk, 2025-01-11:
Is it happening with a particular circuit or all? If particular can you mention it and share its image .

AbhijitBaral, 2025-01-12:
What I figured out is, it happens when the "reference" of an e-sim plot element is changed from it's default "Ux" value.
Also I've had problems during simulation, when I changed the reference name of MOSFETS in a schematic..

AbhijitBaral, 2025-01-12:
So it is best to leave the reference names of elements in KiCad schematics as they are by default.

Closed 2025-01-13.

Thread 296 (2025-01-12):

Adding toggle button to change the plotter from Python Plotter(Matpotlib) to NgSpice and back

092vk, 2025-01-12:
### Description

eSim 2.4 automatically plots using Python(Matplotlib) once the netlist is created, while in earlier versions, NgSpice was used. Many users have complained that the Python plotter breaks sometimes or that they don't like it and want to switch back to NgSpice-based plotting.

So, a toggle button is needed that can change which tool is used for plotting. This button should allow the user to select whether to use Python Plotter or NgSpice.

### Steps to Reproduce
1. Plot in eSim 2.4
2 .Plot the same thing in eSim 2.3

### Expected Behavior
The user should be able to toggle between the Python plotter and the NgSpice plotter, enabling them to select their preferred plotting tool.

### Version and OS
 - eSim  2.4
 - OS: Win 11 & Ubantu 24

AbhijitBaral, 2025-01-13:
I think that is necessary. The e-sim plot elements only make sense when there is a window displaying the selected signals exclusively. The matplotlib though, is useful to keep all the node voltage and current signals in hand.

Closed 2025-05-05.

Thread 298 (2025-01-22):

Cannot convert kicad to ngSpice

Myo-Thinzar, 2025-01-22:
### Description

I attempted to convert KiCad to NGSpice in eSim 2.4. Everything works fine except for the eSim_Analog, eSim_Digital, and eSim_Hybrid components, where this error occurs.

### Steps to Reproduce

Unzip the Project
Open Project  in eSim2.4
Select Project and click  KicadtoNgspice
[FullAdder.zip](https://github.com/user-attachments/files/18500446/FullAdder.zip)

[Half_Adder.zip](https://github.com/user-attachments/files/18500481/Half_Adder.zip)

### Expected Behavior

The Kicad to NgSpice Window should show up.

### Screenshots

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

### Version and OS

 - eSim 2.4
 - OS: Ubuntu 20.04

### Additional Context

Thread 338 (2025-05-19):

Component Search Bar Lag – Very Slow Typing and Search Response in eSim

Parthapnath, 2025-05-19:
### Description

<!--- A clear and concise description of what the bug is. -->
Hi team,

I'm currently using eSim for designing and testing circuits as part of a project. I've noticed a significant usability issue with the component search bar in the GUI:

Whenever I try to type a component name (e.g., "resistor", "PWL", "capacitor", etc.), each letter takes 3–4 seconds to appear in the search bar.

After finishing typing, the results also take another 3–4 seconds to show up.

This happens consistently, even for common components.

The lag makes the process quite slow and frustrating, especially when adding multiple components to the schematic.

### Steps to Reproduce

<!--- This could be a list of actions and possibly the eSim project files -->

1.Open eSim.

2.Create or open any project.

3.Try to add a component using the search bar.

4.Type any component name slowly (e.g., “resistor” or “PWL”).

5.Observe delay in letter appearance and search results.

### Expected Behavior

<!--- A clear and concise description of what you expected to happen. -->

Typing should be responsive and component search results should be displayed almost instantly.

Actual Behavior:

1.Each keystroke takes ~3 seconds to appear.

2.Search results are delayed.

3.Makes the tool slower to use for larger circuit designs.

### Screenshots

<!--- If applicable, add screenshots to help explain your problem. -->

### Version and OS

<!--- Please complete the following information. -->

 - eSim version:  eSim 2.3
 - OS: [e.g. Windows 10, 64 bit]:  Windows 11, 64 bit

### Additional Context

<!--- Add any other context about the problem here. -->

Suggestion:

If possible, optimize the component search bar by:

1. Improving UI responsiveness.

2. Caching component list locally.

3. Possibly reducing redraw/update frequency during typing.

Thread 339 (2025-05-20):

eSim (Version 2.4) Application closes when converting from kicad to ngspice.

Abedee, 2025-05-20:
### Description

When converting from Kicad to Ngspice, the eSIM application closes. I have created the circuit in Eeschema, then exported the Netlist file, but whenever I try to convert from Kicad to Ngspice, the eSIM application closes.

### Steps to Reproduce

I designed the circuit for IC 74hc4072, made the Subcircuit, then made the Test circuit for the same in Eeschema, exported the Netlist file. But when I'm running the kicad to ngspice converter button, the software just closes.

### Expected Behavior

After the export of the netlist file, when I click on kicad to ngspice converter it should open up a dialog box with different options like, what type of analysis I want to do, source details, add .lib file for different components that I am using. add subckt file for the IC etc.

### Screenshots

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, this is the terminal window whenever I click on the Kicad to Ngspice convert button.

### Version and OS

Windows 11, OS 26100.3915

 - eSim version: 2.4
 - OS: Windows 11, 64 bit

### Additional Context

Abedee, 2025-05-20:
[74hc21_MainCktFile.zip](https://github.com/user-attachments/files/20343480/74hc21_MainCktFile.zip)

[74hc21_SubCktFile.zip](https://github.com/user-attachments/files/20343484/74hc21_SubCktFile.zip)

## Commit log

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2022-06-21 Replaced eSim_AC by AC
    Due to the prefix "eSim_", the AC source doesn't appear in the KiCAD_Ngspice Conversion hence the prefix is removed.
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2022-08-11 This includes transmission lines & switch model files in device modelling window
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2022-09-17 fix circuit component element out of range crash
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2022-11-12 cut command fix
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2022-11-27 Log Amplifier IC
    [LOG_Amplifier.sch, lm_741.sch]
2022-11-27 Failed Circuit deleted from master branch
    [LOG_Amplifier.sch, lm_741.sch]
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2023-06-01 Suppressed PrinterOnly error of ngspice batch mode
2023-06-07 sim. process switched to qt slot-signal mech. & report errors
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2023-06-16 Porting kicad v4 to v6 & Coordinate issue solved
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2023-06-20 subcircuiteditor method modified
    In the method subcircuiteditor added a conditional statement to handle the case when projDir is None.
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2024-08-25 SN54HC148 IC- 8:3 Priority Encoder
    [3_and.sch, 4_NOR.sch, 4_and.sch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]
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2024-09-12 Integrated Schematic Converters (#271)
    Add the files for the Schematic Converters(PSpice to KiCad and LTspice to KiCad converters) to eSim.
    [eSim_PSpice_to_KiCad_Python_Parser.sch]
2024-11-19 Subcircuit Files of ICs(Contributor: Sudheshna Prabakaran) (#285)
    * Removed distutils dependency
    shutil can be used in place of distutils .
    * Integrated Schematic Converters (#271)
    * SN7445 is a BCD-To-Decimal Decoders/Drivers
    * LM323A is a 3.0 A Positive Voltage Regulator
    * LM341 is a 500-mA, 35-V, linear voltage regulator
    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
2025-05-30 Fix: Snap X and Y pin coordinates to grid in auto-generated symbols
2025-06-01 Adding LTC6603
    LTC6603 is a 9th Order Dual channel Butterworth Low Pass Filter for cut off frequency of 2.2kHz
2025-06-01 Adding LTC1565-31
    LTC156531 is a 7th Order Butterworth Low Pass Filter for cut off frequency of 6kHz
2025-06-01 Adding MAX7409
    MAX7409 is a 5th Order Switched-Capacitor Bessel Low Pass Filter for cut off frequency of 2.5kHz & Vin of 4V
2025-06-01 Adding MAX7410
    MAX7410 is a 5th Order Switched-Capacitor Butterworth Low Pass Filter for cut off frequency of 2.5kHz & Vin of 4V
2025-06-01 Adding MAX7413
    MAX7413 is a 5th Order Switched-Capacitor Bessel Low Pass Filter for cut off frequency of 2.5kHz & Vin of 2V
2025-06-01 Adding MAX7414
    MAX7414 is 5th Order Switched-Capacitor Butterworth Low Pass Filter for cut off frequency of 2.5kHz & Vin of 2V
2025-06-01 Adding MAX7419
    MAX7419 is a 5th Order Switched-Capacitor Bessel Low Pass Filter for cut off frequency of 6.5kHz
2025-06-01 Adding MAX7420
    MAX7420 is a 5th Order Switched-Capacitor Butterworth Low Pass Filter for cut off frequency of 4.5kHz
2025-06-01 Adding MAX7423
    MAX7423 is a 5th Order Switched-Capacitor Bessel Low Pass Filter for cut off frequency of 7kHz
2025-06-01 Adding MAX7424
    MAX7424 is a 5th Order Switched-Capacitor Butterworth Low Pass Filter for cut off frequency of 5kHz
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2025-07-02 fixing namespace error
    [pyvenv.cfg]
2025-07-02 working on error
    [pyvenv.cfg]
2025-07-05 Oscillator Driver IC
    Oscillator Driver IC
2025-07-05 hex (six) inverting buffer/line driver
    hex (six) inverting buffer/line driver
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2025-08-10 library: kicadLibrary: enable all non-Esim symbols
    As we are packaging Kicad also SO we can add
    our Esim symbols globally.
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2025-08-31 SN74LS697
    SN74LS697 – Synchronous up/down counters with output registers and multiplexed 3 state outputs
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2025-08-31 SN74LVC8T245
    SN74LVC8T245 - 8-Bit Dual-Supply Bus Transceiver With Configurable Voltage Translation and 3-State Outputs
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2026-01-14 LM566 is a VOLTAGE-CONTROLLED OSCILLATOR (VCO) IC.
2026-01-14 LM108 IC
    [LM108.kicad_sch]
2026-01-14 LM393 IC
    [lm393.kicad_sch]
2026-01-14 LM565 IC
    [lm565.kicad_sch]
2026-01-14 UA709c IC
    [ua709c.kicad_sch]
2026-01-14 CA3020 IC
    [CA3020.kicad_sch]
2026-01-14 MC1496 IC
    [MC1496.kicad_sch]
2026-01-14 TL03xA IC
    [TL03xA.kicad_sch]
2026-01-14 LM3080 IC
    [LM3080.kicad_sch]
2026-01-14 NE556 IC
    [DUALTIMER_COMPARATOR.kicad_sch, NE556.kicad_sch]
2026-01-14 UA702m IC
    [UA702M.kicad_sch]
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2026-01-17 MC100EL1648 is a Voltage Controlled Oscillator IC
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2026-01-27 removed duplicate lm393 directory
    [lm393.kicad_sch]
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2026-02-15 feat: Add Universal AppImage builder for multi-distro eSim packaging
    - Automated build script for eSim 2.5 AppImage (~7800 lines)
    - Multi-distro dependency handling (apt, dnf, pacman, zypper)
    - OMEdit library bundling with Ubuntu .deb fallback for Arch/Fedora
    - GHDL automated installation from GitHub releases
    - Qt5 ABI compatibility fixes for Arch Linux
    - ICU 66/70 coexistence for Qt5WebKit
    - Bundled KiCad 6.0.11, NgSpice 35, Verilator, Makerchip
    - Container warning suppression (machine-id, accessibility)
    - Comprehensive README with build instructions and troubleshooting
2026-02-17 Added PLL internship projects:Chargepump, PFD,PLL,VCO,Freq_divider
    [Chargepump.kicad_sch, PFD.kicad_sch, PLL.kicad_sch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]
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2026-02-18 PI3B3384 is a 10-Bit, 2-Port, NanoSwitch
    PI3B3384 is a 10-bit, 2-port bus switches designed with a low On-Resistance allowing inputs to be connected directly to outputs. The bus switch creates no additional propagational delay or additional ground bounce noise. Switches are turned ON by the Bus Enable (BE) input signal. Two bus enable signals are provided, one for each of the upper and lower five bits of the two 10-bit buses
2026-04-07 Added macos support installing folder
    [3_Input_NAND_Characteristics.sch, 3_and.sch, 4002.sch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]
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2026-05-19 fix(pyqt6): fix 5 broken PyQt5 enum/API calls missed in migration
    - QListWidget.MultiSelection → SelectionMode.MultiSelection
    - menu.exec_() → menu.exec()
    - QProcess.SeparateChannels → ProcessChannelMode.SeparateChannels
    - error_type <= int comparison (TypeError) → enum tuple membership check
    - QProcess.NotRunning (×2) → ProcessState.NotRunning in TerminalUi
2026-05-29 Add unit tests for fixInst voltage sources
2026-05-29 Add unit tests for fixInst plot and ground sources
2026-06-02 PyQt6 migration and bug fixes across frontend, kicad, nghdl, and related modules
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2026-06-02 fix(devicemodel): guard all eSim_general_libs branches against short netlist lines
    Malformed SPICE component lines with fewer tokens than expected caused
    IndexError crashes when opening KiCad→Ngspice converter. Added len(words)
    guards on all five device branches (q, d, j, s, m) — short lines are
    silently skipped, consistent with existing try/except BaseException patterns.
    Triggered by SN55451B netlist where diode lines had only 2 tokens (D2 __D2).
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2026-06-08 74LS240 : Octal Inverting Buffer and Line Driver
    74LS240 is an Octal Inverting Buffer and Line Driver IC. It has 8 inverting buffers with 3-state outputs. This subcircuit was designed in eSim, ERC was checked, netlist was generated, KiCad was converted to NgSpice, and input/output plots were verified.
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2026-06-08 SN74LS55 is a 2-Wide 4-Input AND-OR-INVERT Gate
    SN74LS55 is a 2-Wide 4-Input AND-OR-INVERT Gate IC. It performs AND-OR-INVERT logic operation. This subcircuit was designed in eSim, ERC was checked, netlist was generated, KiCad was converted to NgSpice, and input/output plots were verified.
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2026-06-08 Revert "Add subckt and simulation files for IC_74LS31, IC_CD74AC174, IC_CD74H…"
2026-06-10 Add subckt file for IC_74LS31
    [IC_74LS31.kicad_sch]
2026-06-10 Add subckt file for IC_CD74AC174
    [IC_CD74AC174.kicad_sch]
2026-06-10 Add subckt file for IC_CD74HC533
    [IC_CD74HC533.kicad_sch]
2026-06-10 Add subckt file for IC_DM8098
    [IC_DM8098.kicad_sch]
2026-06-10 Add subckt file for IC_GD74HCT58
    [IC_GD74HCT58.kicad_sch]
2026-06-10 Add subckt file for IC_M74HC4024
    [IC_M74HC4024.kicad_sch]
2026-06-10 Add subckt file for IC_MC10E155
    [IC_MC10E155.kicad_sch]
2026-06-10 Add subckt file for IC_MC10E156
    [3_and.sch, 4_OR.sch, IC_MC10E156.kicad_sch]
2026-06-10 Add subckt file for IC_NA53
    [IC_NA53.kicad_sch]
2026-06-10 Add subckt file for IC_OR73
    [IC_OR73.kicad_sch]
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2026-06-13 SN74HC623 is Voltage-Controlled Oscillator IC.
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2026-07-15 Fixes issue #417 - Open .kicad_sch subcircuit schematics in Edit Subcircuit
    Edit Subcircuit always launched eeschema with a hardcoded .sch path.
    Subcircuits saved with KiCad 6 use the .kicad_sch extension, so
    eeschema was pointed at a file that does not exist and kept prompting
    to create a new schematic instead of opening the existing one.
    Pick the .kicad_sch file when it exists and fall back to the legacy
    .sch file otherwise, the same way Kicad.py opens the main project
    schematic. New subcircuits are now created as .kicad_sch directly,
    in line with the project schematics from newProject.py.
2026-07-21 Move CA-series ICs to SubcircuitLibrary and clean generated files
    [CA3018_TEST1.kicad_sch, CA3019_TEST1.kicad_sch, CA3022_TEST1.kicad_sch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]
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2026-08-04 Add files via upload
    Add REF02 subcircuit
    [REF02.kicad_sch]
2026-08-04 Add REF01 subcircuit
    [REF01.kicad_sch]
2026-08-04 Add LM105 subcircuit
    [LM105.kicad_sch]
2026-08-04 Add LM329 subcircuit
    [LM329.kicad_sch]
2026-08-04 Add NCV33078 subcircuit
    [NCV33078.kicad_sch]
2026-08-04 Add TBA820 subcircuit
    [TBA820.kicad_sch]
2026-08-04 Add SN74147 subcircuit
    [74147.kicad_sch]
2026-08-04 Add NE592 subcircuit
    [NE592.kicad_sch]
2026-08-04 Add SN54LS283 subcircuit
    [SN54LS283.kicad_sch]
2026-08-04 Add MC14077B subcircuit
    [SN5428.kicad_sch]
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2026-08-09 Revert "Subcircuit files for ICs by Sanchi Ramteke"
    [74147.kicad_sch, LM105.kicad_sch, LM329.kicad_sch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]
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
